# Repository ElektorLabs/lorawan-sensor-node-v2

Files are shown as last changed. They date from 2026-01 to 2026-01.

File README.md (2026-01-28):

# LoRa-Sensor-Node-v2




A comprehensive ESP32-S3 based sensor node that validates GPS positioning, LoRaWAN connectivity, SD card logging, battery charging, and deep-sleep power management without requiring the Arduino IDE.

## 🚀 Features

- **Multi-Peripheral Validation**: Powers and tests GPS, LoRa modem, SD logger, and battery charger
- **Smart Power Management**: Configurable deep-sleep cycles with peripheral power control
- **LoRaWAN Integration**: OTAA join with synthetic telemetry transmission
- **GPS Cold Start Handling**: Waits for valid GPS fix before LoRaWAN operations
- **Battery Management**: BQ25186 charger monitoring and configuration
- **Comprehensive Logging**: Tagged UART output and SD card data logging
- **Status Indicators**: LED patterns for system health monitoring

## 🔧 Hardware Components

### Core Platform
- **MCU**: ESP32-S3 Development Module
- **GPS Module**: Ebyte EWM108-GN05 (Allystar-compatible GNSS receiver)
- **LoRa Module**: Ebyte LoRaWAN module with AT command interface
- **Battery Charger**: BQ25186 Li-Ion battery management IC
- **Storage**: MicroSD card for data logging

### Pin Configuration

| Component | Pin | Function |
|---|-----|---|
| **Power Control** |
| I2C Enable | GPIO 38 | I2C bus power control |
| LoRa Enable | GPIO 6 | LoRa module power |
| GPS Enable | GPIO 7 | GPS module power |
| **Status LEDs** |
| Red LED | GPIO 48 | Error/fault indication |
| Green LED | GPIO 47 | System status |
| **I2C Bus** |
| SDA | GPIO 10 | I2C data line |
| SCL | GPIO 9 | I2C clock line |
| **SD Card (SPI)** |
| MOSI | GPIO 11 | SPI data out |
| SCK | GPIO 12 | SPI clock |
| MISO | GPIO 13 | SPI data in |
| CS | GPIO 8 | Chip select |
| **LoRa UART** |
| RX | GPIO 4 | LoRa module RX |
| TX | GPIO 5 | LoRa module TX |
| **GPS UART** |
| RX | GPIO 21 | GPS module RX |
| TX | GPIO 14 | GPS module TX |

## ⚙️ Configuration

All configuration is centralized in `config.h` using `constexpr` constants:

### Timing Parameters
```cpp
constexpr unsigned long kGpsColdStartMs = 60000;        // GPS cold start window
constexpr unsigned long kGpsLockTimeoutMs = 180000;     // GPS fix timeout
constexpr unsigned long kSensorAcquisitionMs = 15000;   // Sensor reading time
constexpr uint64_t kDeepSleepIntervalUs = 60ULL * 1000000ULL; // Sleep interval
constexpr unsigned long kLoraJoinRetryMs = 15000;       // LoRa join retry
```

### Power Management
```cpp
constexpr bool kEnableDeepSleep = true;     // Enable ESP32 deep sleep
constexpr bool kEnableStatusLeds = true;    // Enable LED indicators
constexpr float kChargeTargetCurrentMa = 520.0f;   // Battery charge current (5-1000 mA)
constexpr float kInputCurrentLimitMa = 665.0f;     // Input current limit (50-665 mA)
```

### LoRaWAN Credentials
```cpp
constexpr LoraCredentials kLoraCredentials{
    "xxxxxxxxxxxxxxxx",                    // Device EUI
    "0000000000000000",                    // Application EUI
    "xxxxxxxxxxxxxxxxxxxxxxxxxxxxxx",   // Application Key
};
```

### GPS Power Configuration
```cpp
constexpr AllystarGpsPowerConfig kGpsPowerConfig{
    true,    // Enable GPS sleep/wake commands
    90000,   // Sleep duration (90 seconds)
    0x01,    // Sleep action (deep sleep)
    0x11,    // Wake mode (start command)
};
```

## 🔄 Operation Flow

1. **System Wake**: ESP32 wakes from deep sleep, powers peripheral rails
2. **GPS Cold Start**: Waits for GPS module to acquire satellite fix
3. **LoRaWAN Join**: Performs OTAA join once GPS is ready (or timeout expires)
4. **Data Collection**: Gathers GPS coordinates and battery telemetry
5. **Transmission**: Sends telemetry via LoRaWAN uplink
6. **Logging**: Records data to SD card with timestamps
7. **Sleep Preparation**: Powers down GPS with Allystar sleep commands
8. **Deep Sleep**: ESP32 enters deep sleep for configured interval

## 📊 Serial Output

The firmware provides tagged serial output at 115200 baud:

```
[Pwr ] Wake reason: Timer
[GPS ] Powering GPS module...
[LoRa] Powering LoRa module...
[GPS ] NMEA: $GNGGA,123456.00,4012.34567,N,07412.34567,W,1,08,1.2,45.6,M,33.2,M,,*5A
[LoRa] AT+JOIN
[LoRa] Event: join confirmed
[LoRa] Sending telemetry: 4012.34567,-07412.34567,45.6,4.12,85
[Chg ] Battery: 4.12V, Charge: 85%, Temp: 25°C
[Pwr ] Entering deep sleep for 60 seconds
```

## 📁 File Structure

```
LoRa-SenseNode-v2/
├── LoRa-SenseNode-v2.ino    # Main firmware file
├── config.h                 # Configuration constants
├── Bq25186.h               # Battery charger interface
├── EbyteGpsParser.h        # GPS NMEA parser
├── LoraAtHelpers.h         # LoRaWAN AT command helpers
├── SdCardLogger.h          # SD card logging utilities
├── TaggedStream.h          # Serial output tagging
├── ProcessFlow.md          # Detailed process documentation
├── FirmwareOverview.md     # Architecture overview
└── docs/                   # Additional documentation
```

## 🔍 Troubleshooting

### LED Status Indicators
- **2 Red Blinks**: GPS fault or timeout
- **3 Red Blinks**: LoRa communication fault
- **Green Solid**: System operating normally
- **LEDs Off**: Status LEDs disabled in config

### Common Issues
1. **GPS Not Acquiring Fix**: Ensure clear sky view, check antenna connection
2. **LoRa Join Fails**: Verify credentials and gateway availability
3. **SD Card Errors**: Check card formatting (FAT32) and connections
4. **Power Issues**: Verify battery connection and charger configuration

### Debug Mode
Set `kEnableDebugSerial = true` and `kShowRawGps = true` in config.h for verbose output.

## 🛠️ Development

### Adding New Features
- Hardware tests: Create new sketches in `src/tests/<SketchName>/`
- Experiments: Use `src/claude-test/` for exploratory code
- Helper functions: Add to existing headers or create new ones as needed

### Testing Without Deep Sleep
Set `kEnableDeepSleep = false` in config.h to run continuous loops for bench testing.

## 📄 License

This project is licensed under the GNU License - see the [LICENSE](LICENSE) file for details.

## 🤝 Contributing

1. Fork the repository
2. Create a feature branch (`git checkout -b feature/amazing-feature`)
3. Commit your changes (`git commit -m 'Add amazing feature'`)
4. Push to the branch (`git push origin feature/amazing-feature`)
5. Open a Pull Request

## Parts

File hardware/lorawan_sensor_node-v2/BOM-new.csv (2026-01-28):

# | Reference | Qty | Manufacturer_Part_Number | Value | DNP | Exclude from BOM | Exclude from Board | Footprint | Datasheet | Mouser Part Number
1 | AE1 | 1 | 3-1478978-1 | 3-1478978-1 |  |  |  | SamacSys_Parts:314789781 | ~ | 571-3-1478978-1
2 | C1 | 1 | C1608X7R1H104K080AA | 100nF |  |  |  | Capacitor_SMD:C_0603_1608Metric | ~ | 810-C1608X7R1H104K
3 | C4 | 1 | C0402C103K5RAC7411 | 10nF |  |  |  | Capacitor_SMD:C_0402_1005Metric_Pad0.74x0.62mm_HandSolder | 80-C0402C103K5R7411 | 80-C0402C103K5R7411
4 | C5 | 1 | C1608X7R1H104K080AA | 0.1uF |  |  |  | Capacitor_SMD:C_0603_1608Metric | ~ | 810-C1608X7R1H104K
5 | C6 | 1 | 865080442004 | 22uF |  |  |  | SamacSys_Parts:CAPAE530X550N |  | 710-865080442004
6 | C7 | 1 | GRM219R60J476ME44 | 47uF |  |  |  | Capacitor_SMD:C_0805_2012Metric | ~
7 | C9 | 1 | GRM187R61A226ME15 | 22uF |  |  |  | Capacitor_SMD:C_0603_1608Metric | ~
8 | C13 | 1 | GRM155R60J475ME47D | 0.1uF |  |  |  | Capacitor_SMD:C_0402_1005Metric_Pad0.74x0.62mm_HandSolder | ~ | 81-GRM155R60J475ME7D
9 | C14 | 1 | GRM155R60J475ME47D | 100nF |  |  |  | Capacitor_SMD:C_0402_1005Metric_Pad0.74x0.62mm_HandSolder | ~ | 81-GRM155R60J475ME7D
10 | C15 | 1 | 600S560KT250T | 56pF |  |  |  | Capacitor_SMD:C_0603_1608Metric_Pad1.08x0.95mm_HandSolder | RF Capacitor | 581-600S560KT250T
11 | C16 | 1 | FM0V104ZF | FM0V104ZF |  |  |  | SamacSys_Parts:FM0V104ZF | https://content.kemet.com/datasheets/KEM_S6012_FM.pdf | 80-FM0V104ZF
12 | C18 | 1 | GRM155R60J475ME47D | 4.7uF |  |  |  | Capacitor_SMD:C_0402_1005Metric_Pad0.74x0.62mm_HandSolder | ~ | 81-GRM155R60J475ME7D
13 | C10,C11 | 2 | GRM155R60J475ME47D | 1uF |  |  |  | Capacitor_SMD:C_0402_1005Metric_Pad0.74x0.62mm_HandSolder | ~ | 81-GRM155R60J475ME7D
14 | C2,C3 | 2 | C0805C104M5RACTU | 0.1uF |  |  |  | Capacitor_SMD:C_0805_2012Metric_Pad1.18x1.45mm_HandSolder | ~ | 80-C0805C104M5R
15 | C8,C12,C17 | 3 | GRM155R60J475ME47D | 10uF |  |  |  | Capacitor_SMD:C_0402_1005Metric_Pad0.74x0.62mm_HandSolder | ~ | 81-GRM155R60J475ME7D
16 | D1 | 1 | SMF05C.TCT | SMF05C.TCT |  |  |  | SamacSys_Parts:SOT65P210X110-6N | https://www.mouser.co.uk/datasheet/2/761/smf05c-1278099.pdf | 947-SMF05C.TCT
17 | D4 | 1 | PMEG2010ER,115 | PMEG2010ER,115 |  |  |  | SamacSys_Parts:PMEG2010ER115 | ~ | 771-PMEG2010ER115
18 | D2,D3 | 2 | CUHS20S30,H3F | CUHS20S30,H3F |  |  |  | SamacSys_Parts:CUHS20S40H3F |  | 757-CUHS20S30H3F
19 | IC1 | 1 | TPL5110QDDCRQ1 | TPL5110QDDCRQ1 |  |  |  | SamacSys_Parts:SOT95P280X110-6N | http://www.ti.com/lit/gpn/tpl5110-q1 | 595-TPL5110QDDCRQ1
20 | IC2 | 1 | TPS22917DBV | TPS22917DBV (L) |  |  |  | Package_TO_SOT_SMD:SOT-23-6 | http://www.ti.com/lit/ds/symlink/tps22917.pdf
21 | IC3 | 1 | TPS631000DRLR | TPS631000DRLR |  |  |  | SamacSys_Parts:SOTFL50P160X60-8N | https://www.ti.com/lit/ds/symlink/tps631000.pdf?ts=1652152702265 | 595-TPS631000DRLR
22 | IC4 | 1 | BQ25186DLHR | BQ25186DLHR |  |  |  | SamacSys_Parts:SON40P220X200X80-11N | https://www.ti.com/lit/ds/symlink/bq25186.pdf?ts=1740508135755 | 595-BQ25186DLHR
23 | IC5,IC6,IC7 | 3 | TPS22919DCKR | TPS22919DCKR |  |  |  | SamacSys_Parts:SOT65P210X110-6N | http://www.ti.com/lit/ds/symlink/tps22919.pdf | 595-TPS22919DCKR
24 | K2 | 1 | PinHeader_2x03_P2.54mm_Vertical | PROG |  |  |  | Connector_PinHeader_2.54mm:PinHeader_2x03_P2.54mm_Vertical | ~
25 | K5 | 1 | JST_SH_SM04B-SRSS-TB_1x04-1MP_P1.00mm_Horizontal | Qwiic |  |  |  | Connector_JST:JST_SH_SM04B-SRSS-TB_1x04-1MP_P1.00mm_Horizontal | ~
26 | K6 | 1 | MEM2085-00-115-00-A | MEM2085-00-115-00-A |  |  |  | SamacSys_Parts:MEM20850011500A | https://gct.co/files/drawings/mem2085.pdf | 640-MEM20850011500A
27 | K7 | 1 | JST_PH_S2B-PH-K_1x02_P2.00mm_Horizontal | Solar Panel |  |  |  | Connector_JST:JST_PH_S2B-PH-K_1x02_P2.00mm_Horizontal | ~
28 | K8 | 1 | UJ20-C-H-C-3-SMT-TR | UJ20-C-H-C-3-SMT-TR |  |  |  | External Library:CUI_UJ20-C-H-C-3-SMT-TR
29 | K9 | 1 | JST_PH_S2B-PH-K_1x02_P2.00mm_Horizontal | Battery |  |  |  | Connector_JST:JST_PH_S2B-PH-K_1x02_P2.00mm_Horizontal | ~
30 | K10 | 1 | Connector_JST:JST_PH_S4B-PH-SM4-TB_1x04-1MP_P2.00mm_Horizontal | LORA UART |  |  |  | Connector_JST:JST_PH_S4B-PH-SM4-TB_1x04-1MP_P2.00mm_Horizontal | ~
31 | K12 | 1 | Connector_JST:JST_PH_S4B-PH-SM4-TB_1x04-1MP_P2.00mm_Horizontal | GPS UART |  |  |  | Connector_JST:JST_PH_S4B-PH-SM4-TB_1x04-1MP_P2.00mm_Horizontal | ~
32 | K1,K3,K4 | 3 | JST_PH_S4B-PH-SM4-TB_1x04-1MP_P2.00mm_Horizontal | IO |  |  |  | Connector_JST:JST_PH_S4B-PH-SM4-TB_1x04-1MP_P2.00mm_Horizontal | ~
33 | L1 | 1 | DFE201610P-1R0M=P2 | 1uH |  |  |  | SamacSys_Parts:1285ASH1R0MP2 | ~ | 81-DFE201610P-1R0MP2
34 | L2 | 1 | AIMC-0402-82NJ-T | AIMC-0402-82NJ-T |  |  |  | SamacSys_Parts:INDC1005X65N | ~
35 | LED1 | 1 | NCD0805G1 | NCD0805G1 |  |  |  | LED_SMD:LED_0805_2012Metric_Pad1.15x1.40mm_HandSolder | ~
36 | LED2 | 1 | NCD0805R1 | NCD0805R1 |  |  |  | LED_SMD:LED_0805_2012Metric_Pad1.15x1.40mm_HandSolder | ~
37 | MOD1 | 1 | ESP32-S3-WROOM-1 | ESP32-S3-WROOM-1 |  |  |  | RF_Module:ESP32-S3-WROOM-1 | https://www.espressif.com/sites/default/files/documentation/esp32-s3-wroom-1_wroom-1u_datasheet_en.pdf
38 | MOD2 | 1 | RAK3172 | ~ |  |  |  | RF_Module:RAK3172
39 | MOD3 | 1 | EWM108-GN05 | EWM108-GN05 |  |  |  | EWM108-GN05:PCBComponent_1 | https://www.cdebyte.com/products/EWM108-GN05/2#Pin
40 | R9 | 1 | RK73H1ETTP5762F | 57k |  |  |  | Resistor_SMD:R_0402_1005Metric | ~ | 660-RK73H1ETTP5762F
41 | R10 | 1 | CRCW040224R0FKED | 24R |  |  |  | Resistor_SMD:R_0402_1005Metric | ~ | 71-CRCW040224R0FKED
42 | R11 | 1 | ERJ-2RKF5113X | 511k |  |  |  | Resistor_SMD:R_0402_1005Metric | ~ | 667-ERJ-2RKF5113X
43 | R12 | 1 | ERJ-2RKF9102X | 91k |  |  |  | Resistor_SMD:R_0402_1005Metric | ~ | 667-ERJ-2RKF9102X
44 | R15 | 1 | RCS06034K70FKEA | 10k |  |  |  | Resistor_SMD:R_0402_1005Metric | ~ | 71-RCS06034K70FKEA
45 | R1,R2,R4,R16 | 4 | RCS060310K0FKEA | 10k |  |  |  | Resistor_SMD:R_0603_1608Metric | ~ | 71-RCS060310K0FKEA,71-RCS060310K0JNEA
46 | R13,R14 | 2 | RCS06034K70FKEA | 4.7k |  |  |  | Resistor_SMD:R_0603_1608Metric | ~ | 71-RCS06034K70FKEA
47 | R3,R5,R8 | 3 | MCT0603PD1000DP500 | 100R |  |  |  | Resistor_SMD:R_0603_1608Metric | ~ | 594-MCT0603PD1000DP5
48 | R6,R7 | 2 | CHP0805-FX-1001ELF | 1k |  |  |  | Resistor_SMD:R_0805_2012Metric_Pad1.20x1.40mm_HandSolder | ~ | 652-CHP0805FX1001ELF
49 | SW1 | 1 | SKRKAEE020 | BOOT |  |  |  | SamacSys_Parts:SKRKAEE020 | ~ | SKRKAEE020
50 | SW2 | 1 | SKRKAEE020 | EN |  |  |  | SamacSys_Parts:SKRKAEE020 | ~ | SKRKAEE020
51 | SW3 | 1 | SKRKAEE020 | WAKE UP |  |  |  | SamacSys_Parts:SKRKAEE020 | ~ | SKRKAEE020
52 | T1 | 1 | IRLML9301TRPBF | IRLML9301TRPBF |  |  |  | SamacSys_Parts:SOT95P237X112-3N | http://www.infineon.com/dgdl/irlml9301pbf.pdf?fileId=5546d462533600a401535668e5e42640 | 942-IRLML9301TRPBF

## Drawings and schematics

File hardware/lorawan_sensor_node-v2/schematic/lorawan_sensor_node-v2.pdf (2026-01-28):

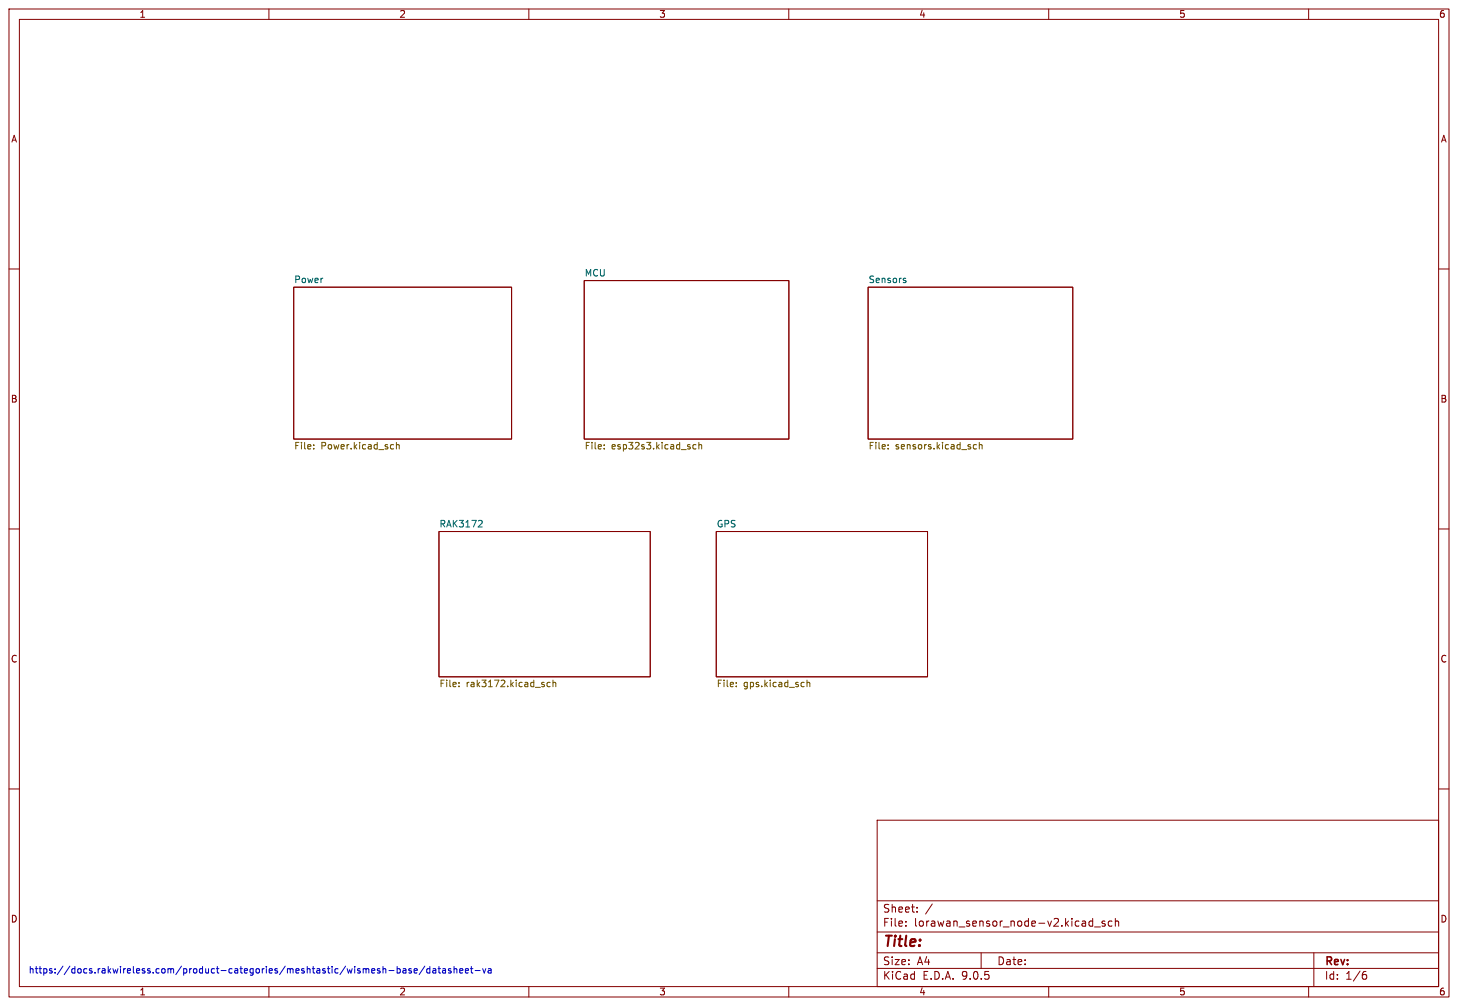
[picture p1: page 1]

https://docs.rakwireless.com/product-categories/meshtastic/wismesh-base/datasheet-va

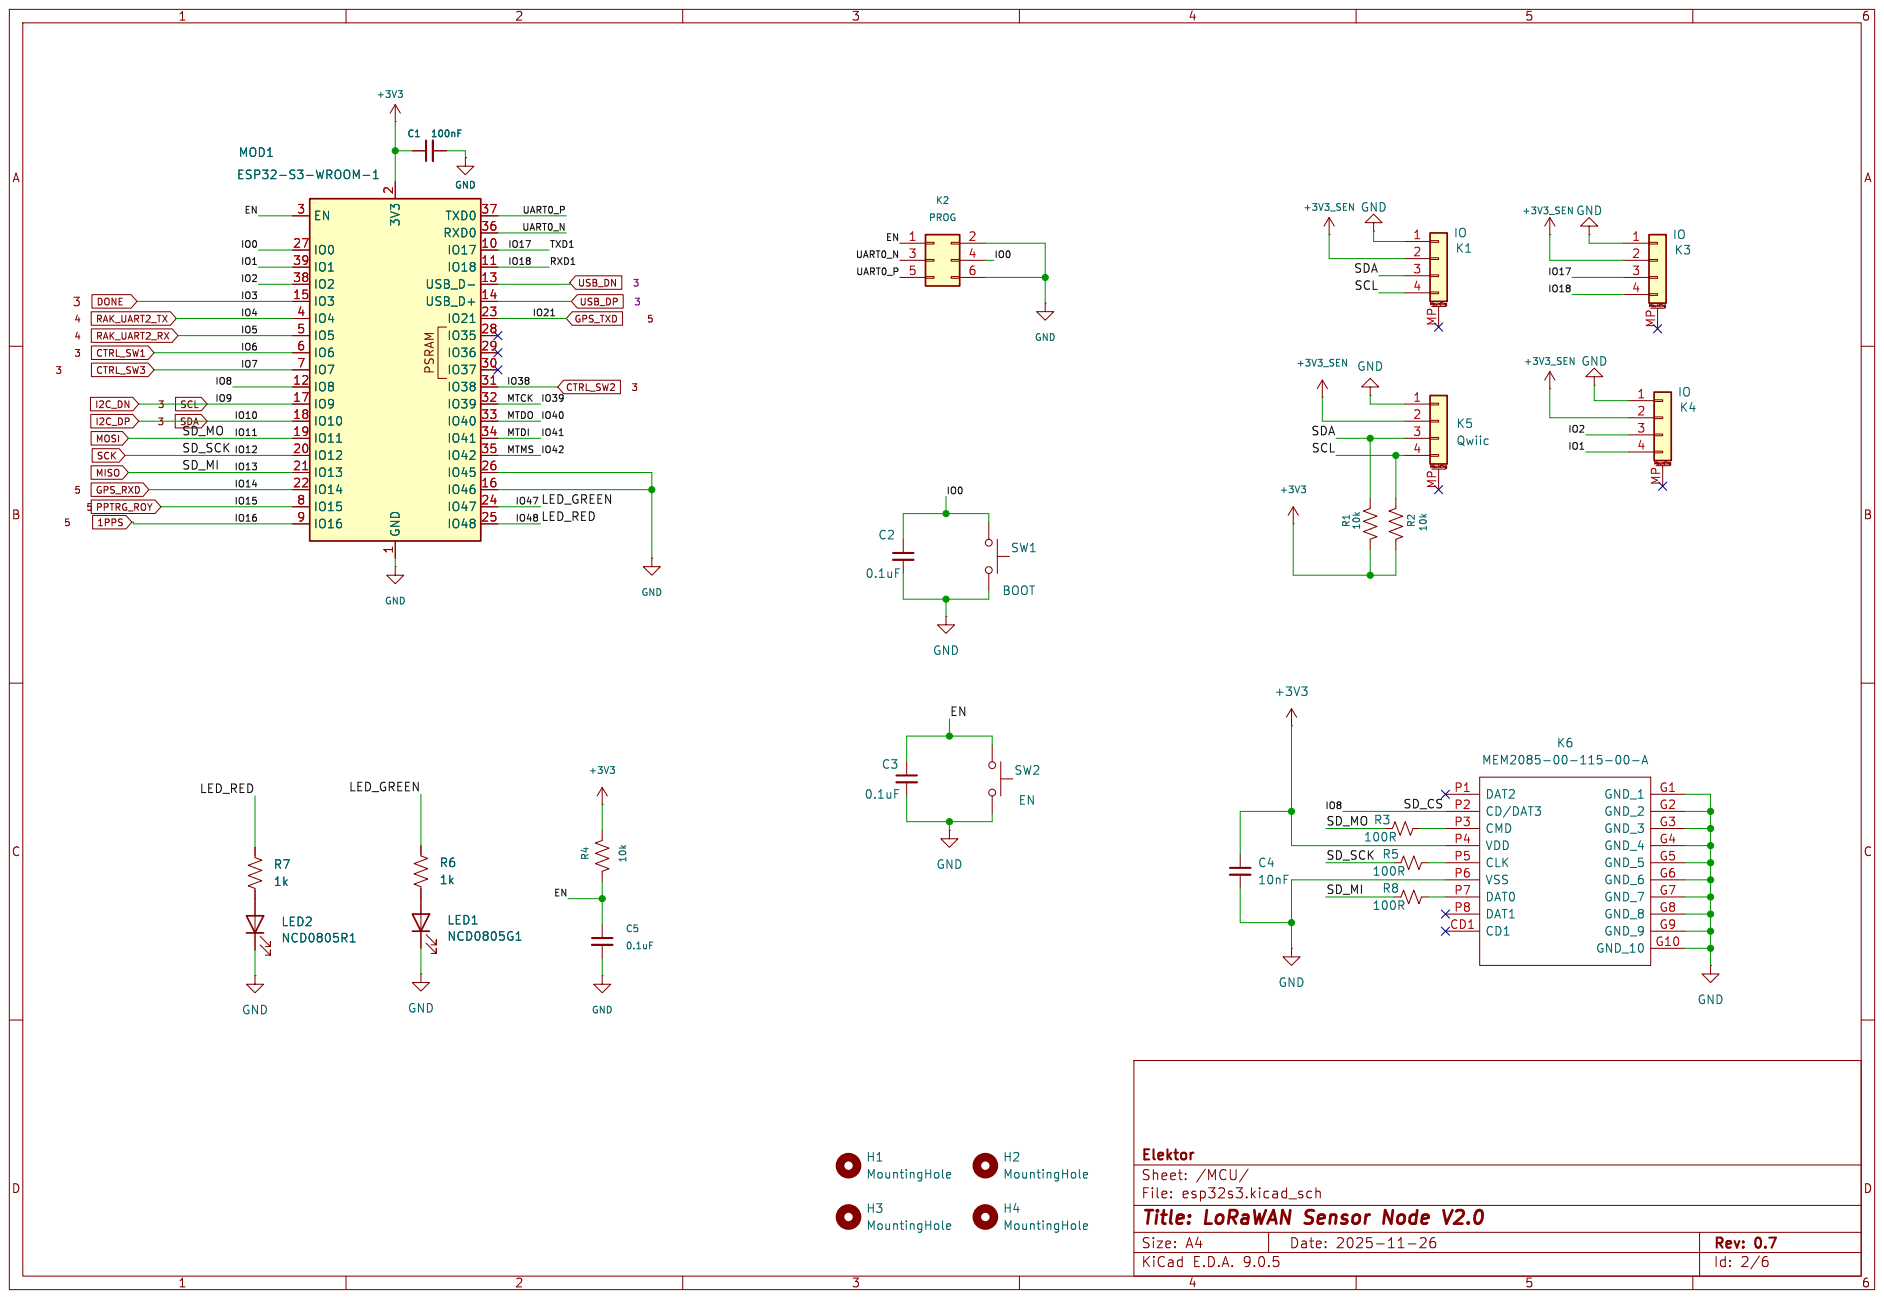
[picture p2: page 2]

File: esp32s3.kicad_sch Sheet: /MCU/ Elektor

Id: 2/6 Title: LoRaWAN Sensor Node V2.0

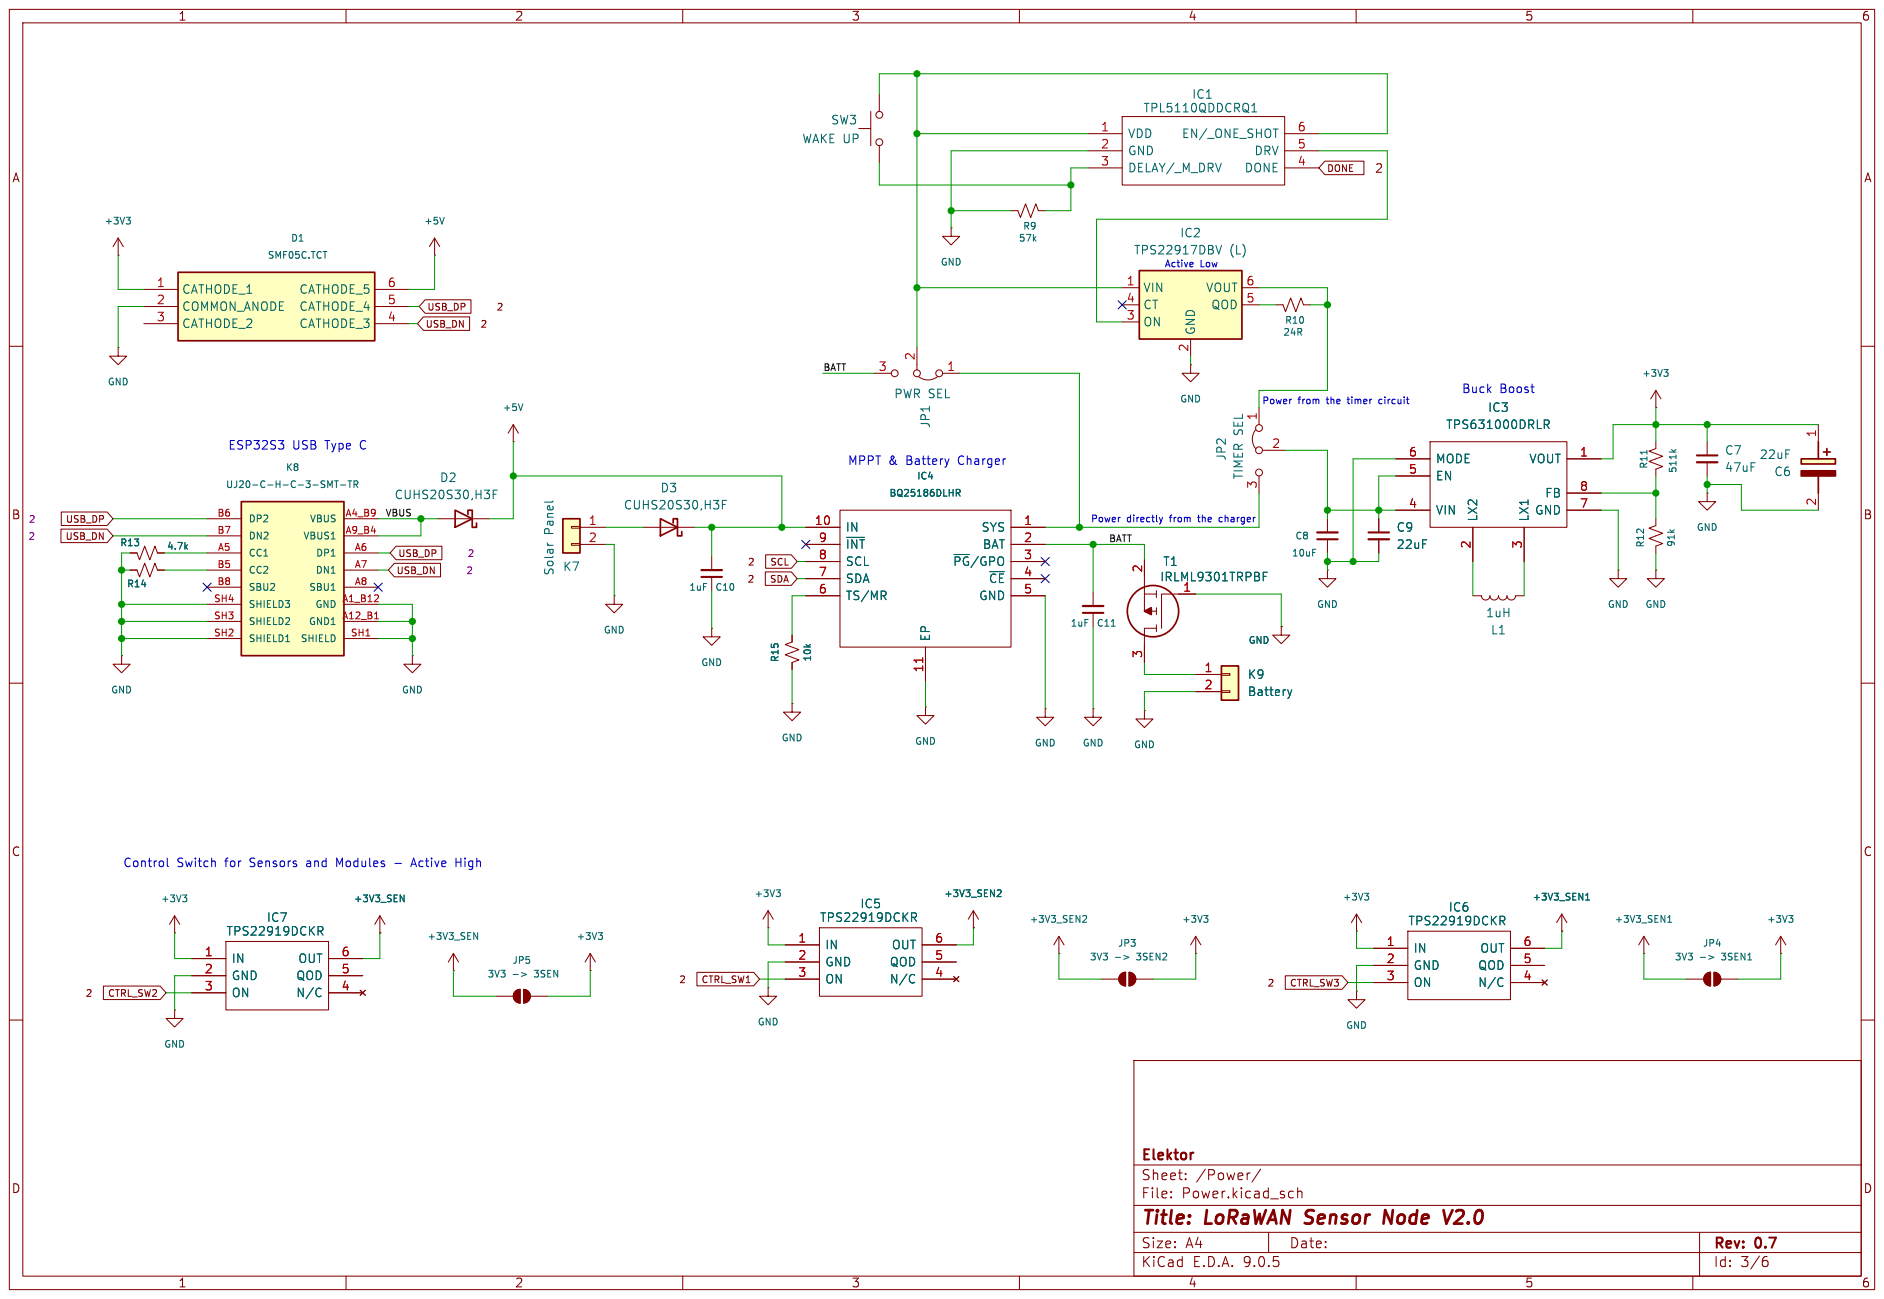
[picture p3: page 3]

File: Power.kicad_sch Sheet: /Power/ Elektor

Id: 3/6 Title: LoRaWAN Sensor Node V2.0

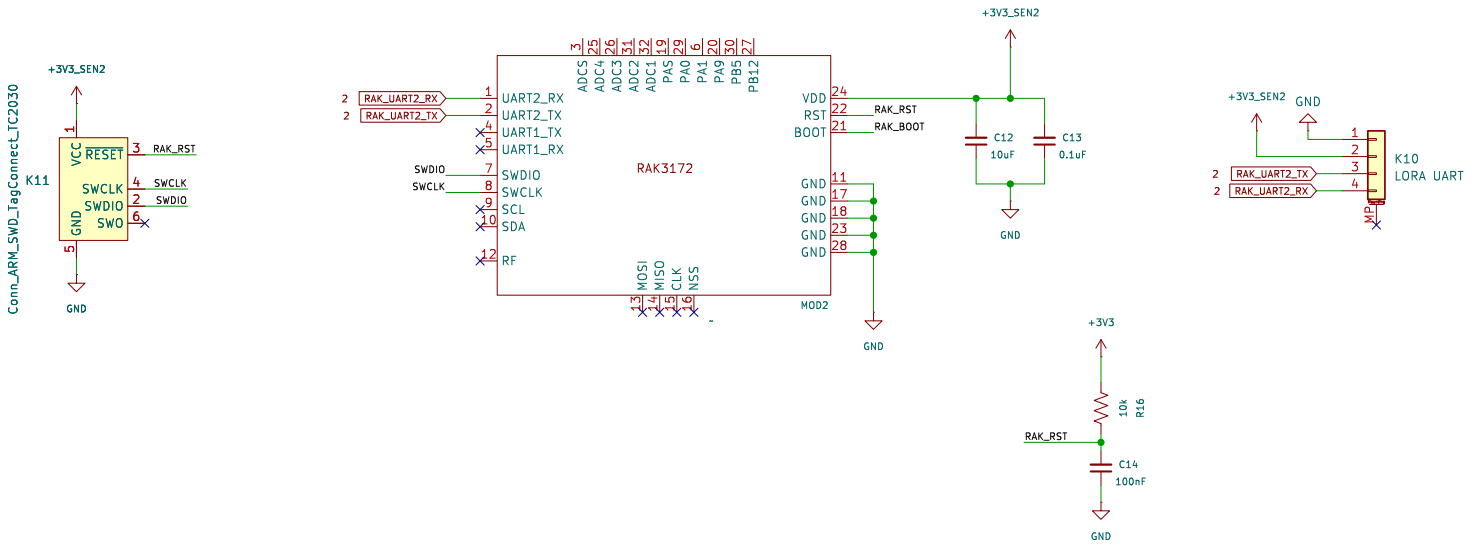
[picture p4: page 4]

3 ADC4 25 ADC3 26 ADC2 31 MOSI 13 ADC1 32 MISO 14 PAS 19 CLK 15 PA0 29 NSS 16 PA1

6 PA9 20 PB5 30 PB12 27 VDD 24 RST 22 BOOT 21 GND 11 GND 17 GND 18 GND 23 GND 28 MOD2 ~

5 ~{RESET}3 SWCLK 4 SWDIO 2 SWO 6 K11 Conn_ARM_SWD_TagConnect_TC2030 2 RAK_UART2_RX

5 ~{RESET}3 SWCLK 4 SWDIO 2 SWO 6 GND

Id: 4/6 Title: LoRaWAN Sensor Node V2.0

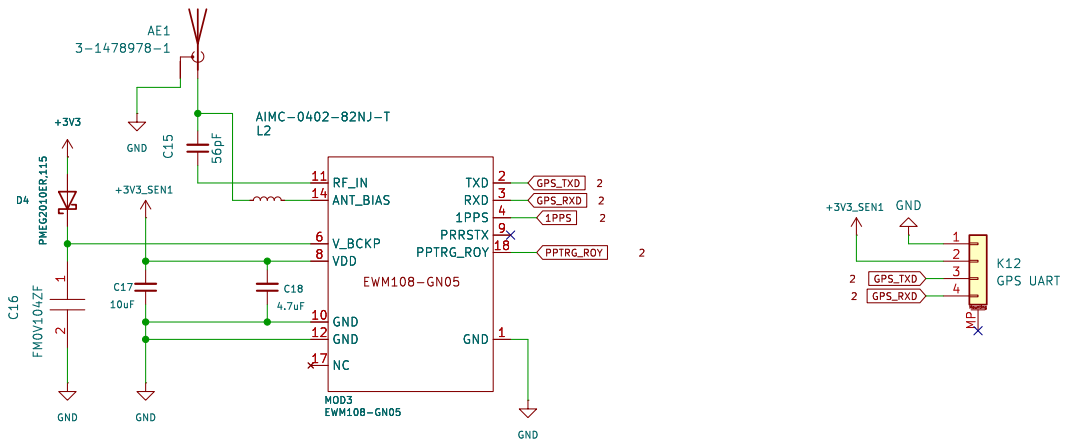
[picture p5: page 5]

Id: 5/6 Title: LoRaWAN Sensor Node V2.0

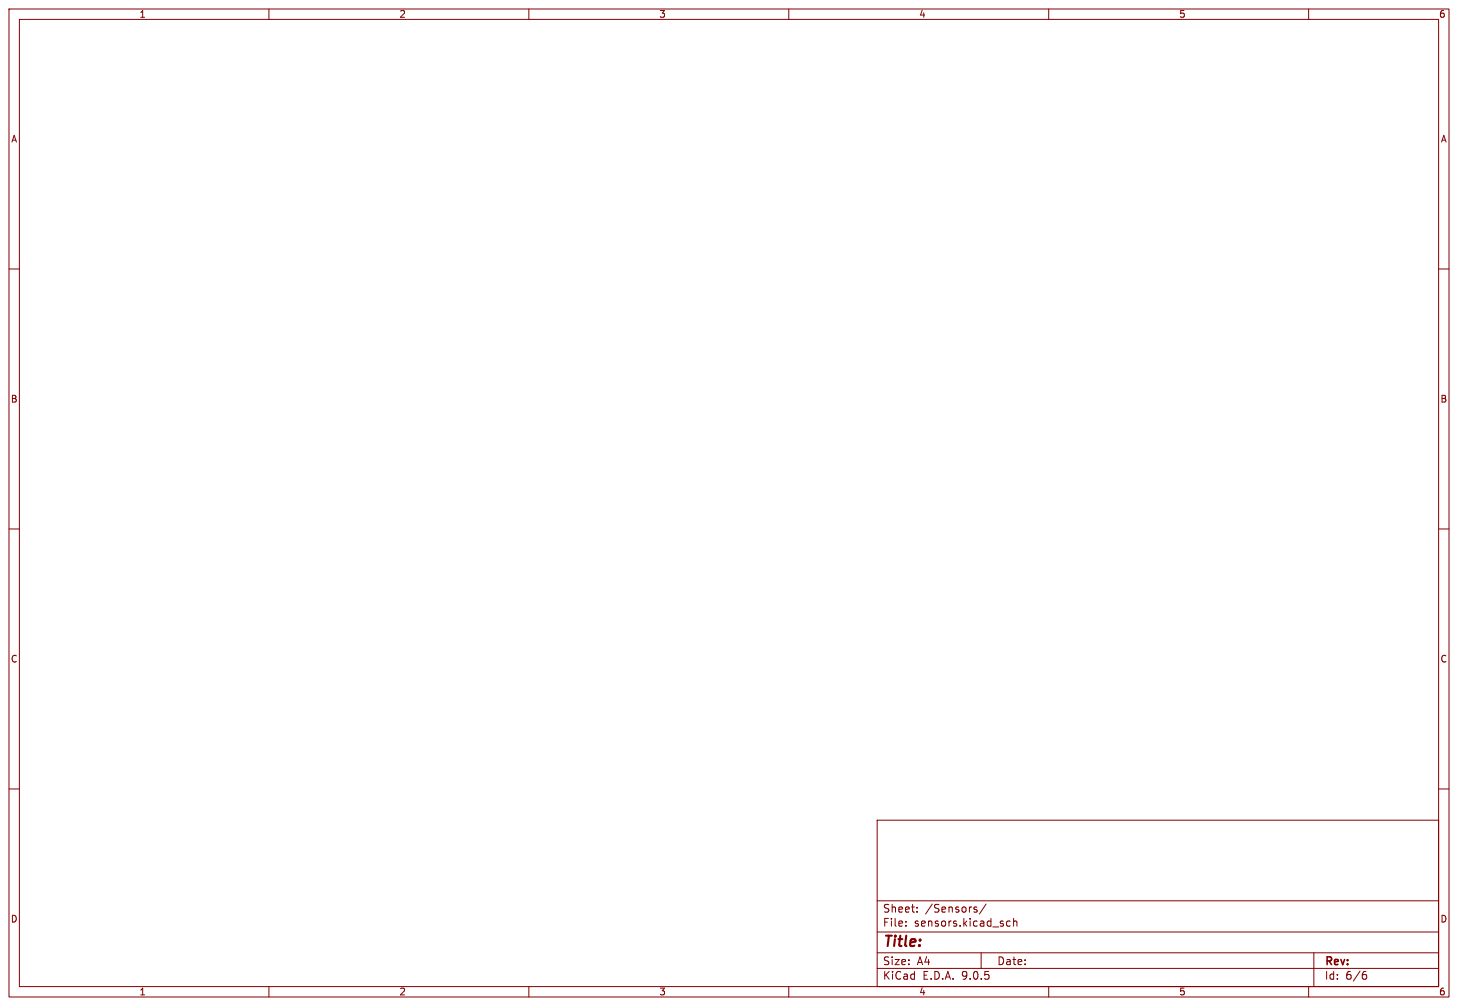
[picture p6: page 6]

Id: 6/6 Title: File: sensors.kicad_sch Sheet: /Sensors/

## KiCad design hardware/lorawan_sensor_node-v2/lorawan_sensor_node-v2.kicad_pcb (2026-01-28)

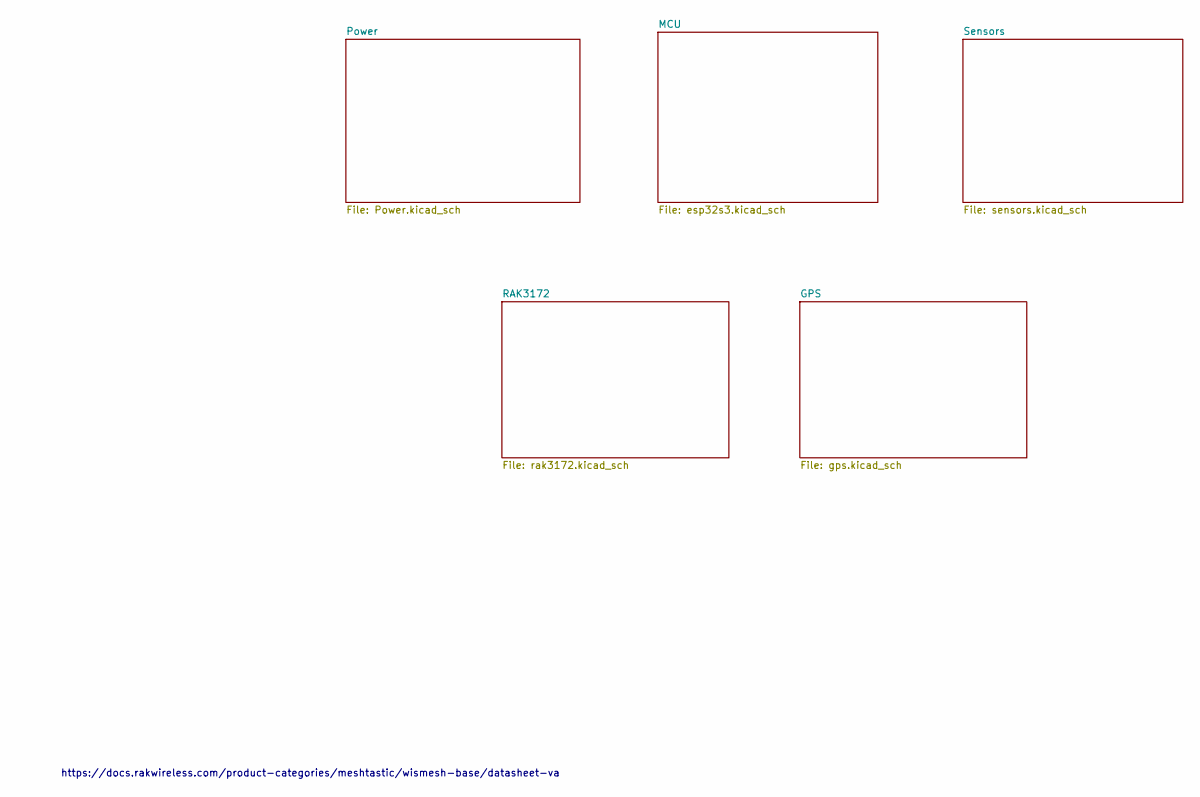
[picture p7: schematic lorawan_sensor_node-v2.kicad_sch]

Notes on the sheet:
https://docs.rakwireless.com/product-categories/meshtastic/wismesh-base/datasheet-va

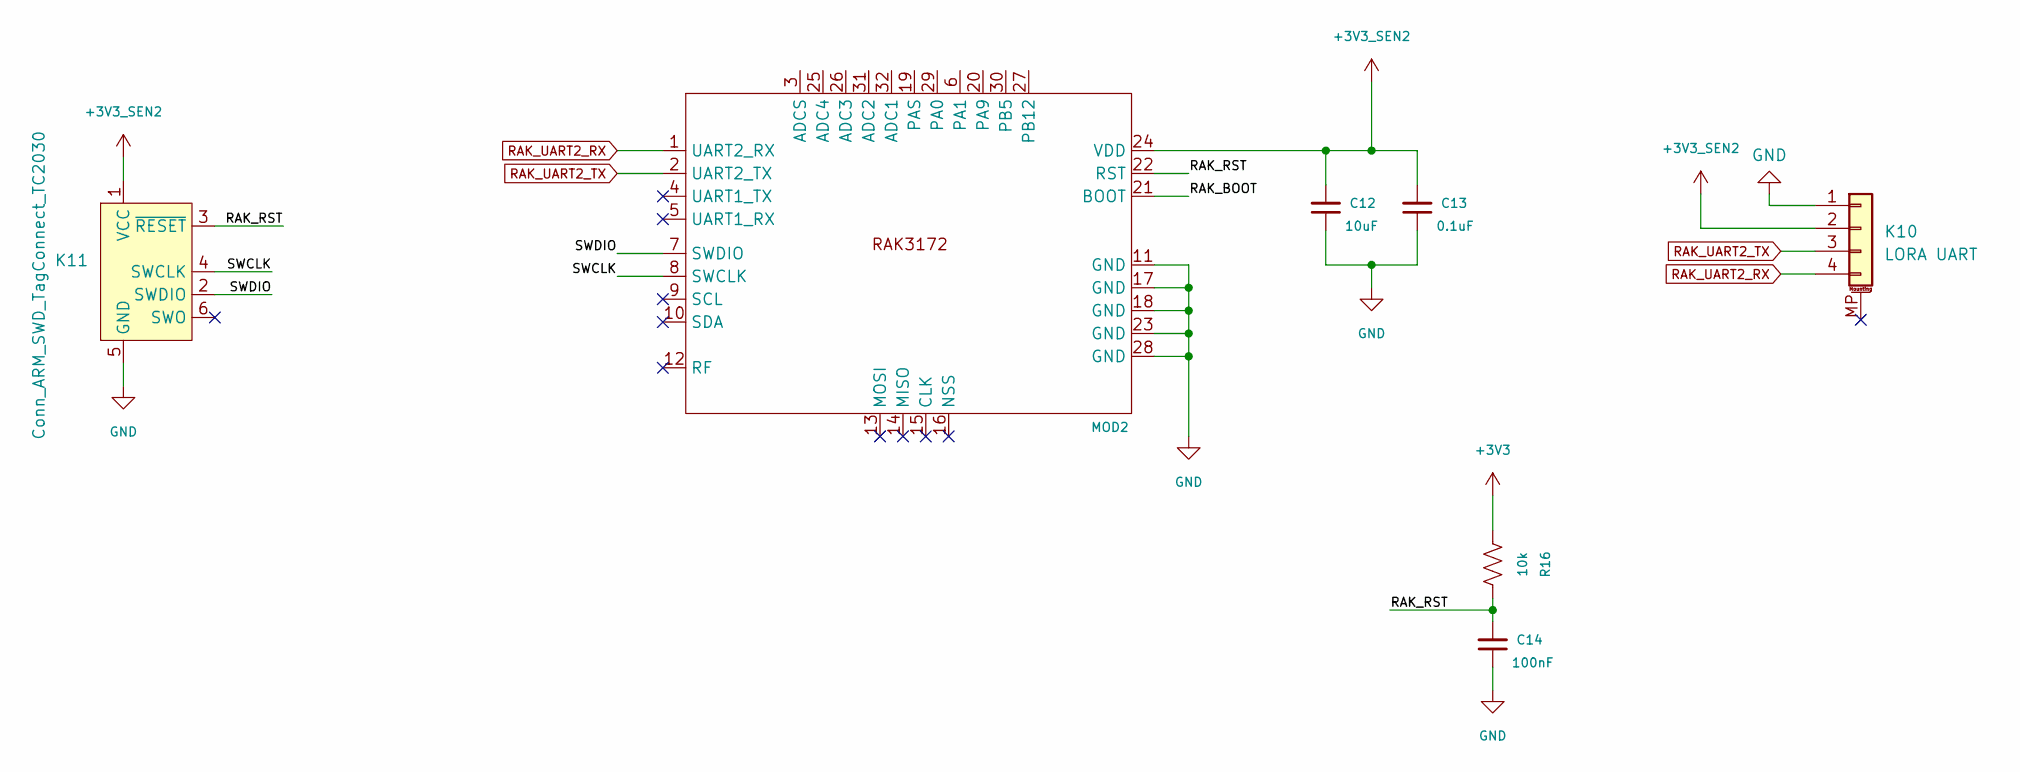
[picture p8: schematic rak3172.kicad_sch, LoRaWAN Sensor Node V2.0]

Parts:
C12: 10uF; C_0402_1005Metric_Pad0.74x0.62mm_HandSolder; Mouser Part Number 81-GRM155R60J475ME7D
C13: 0.1uF; C_0402_1005Metric_Pad0.74x0.62mm_HandSolder; Mouser Part Number 81-GRM155R60J475ME7D
C14: 100nF; C_0402_1005Metric_Pad0.74x0.62mm_HandSolder; Mouser Part Number 81-GRM155R60J475ME7D
K10: LORA UART; JST_PH_S4B-PH-SM4-TB_1x04-1MP_P2.00mm_Horizontal; Manufacturer_Part_Number Connector_JST:JST_PH_S4B-PH-SM4-TB_1x04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
K11: Conn_ARM_SWD_TagConnect_TC2030; Tag-Connect_TC2030-IDC-NL_2x03_P1.27mm_Vertical
MOD2: RAK3172; Manufacturer_Part_Number RAK3172
R16: 10k; R_0603_1608Metric; Manufacturer_Part_Number RCS060310K0FKEA; Mouser Part Number 71-RCS060310K0FKEA

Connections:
+3V3: R16.2; also elsewhere on the board
+3V3_SEN2: C12.2, C13.2, K10.2, K11.1 (VCC), MOD2.24 (VDD); also elsewhere on the board
/RAK3172/RAK_BOOT: MOD2.21 (BOOT)
/RAK3172/RAK_RST: C14.2, K11.3 (~RESET), MOD2.22 (RST), R16.1
/RAK3172/SWCLK: K11.4 (SWCLK), MOD2.8 (SWCLK)
/RAK3172/SWDIO: K11.2 (SWDIO), MOD2.7 (SWDIO)
GND: C12.1, C13.1, C14.1, K10.1, K11.5 (GND), MOD2.11 (GND), MOD2.17 (GND), MOD2.18 (GND), MOD2.23 (GND), MOD2.28 (GND); also elsewhere on the board
RAK_UART2_RX: K10.4, MOD2.1 (UART2_RX); also elsewhere on the board
RAK_UART2_TX: K10.3, MOD2.2 (UART2_TX); also elsewhere on the board

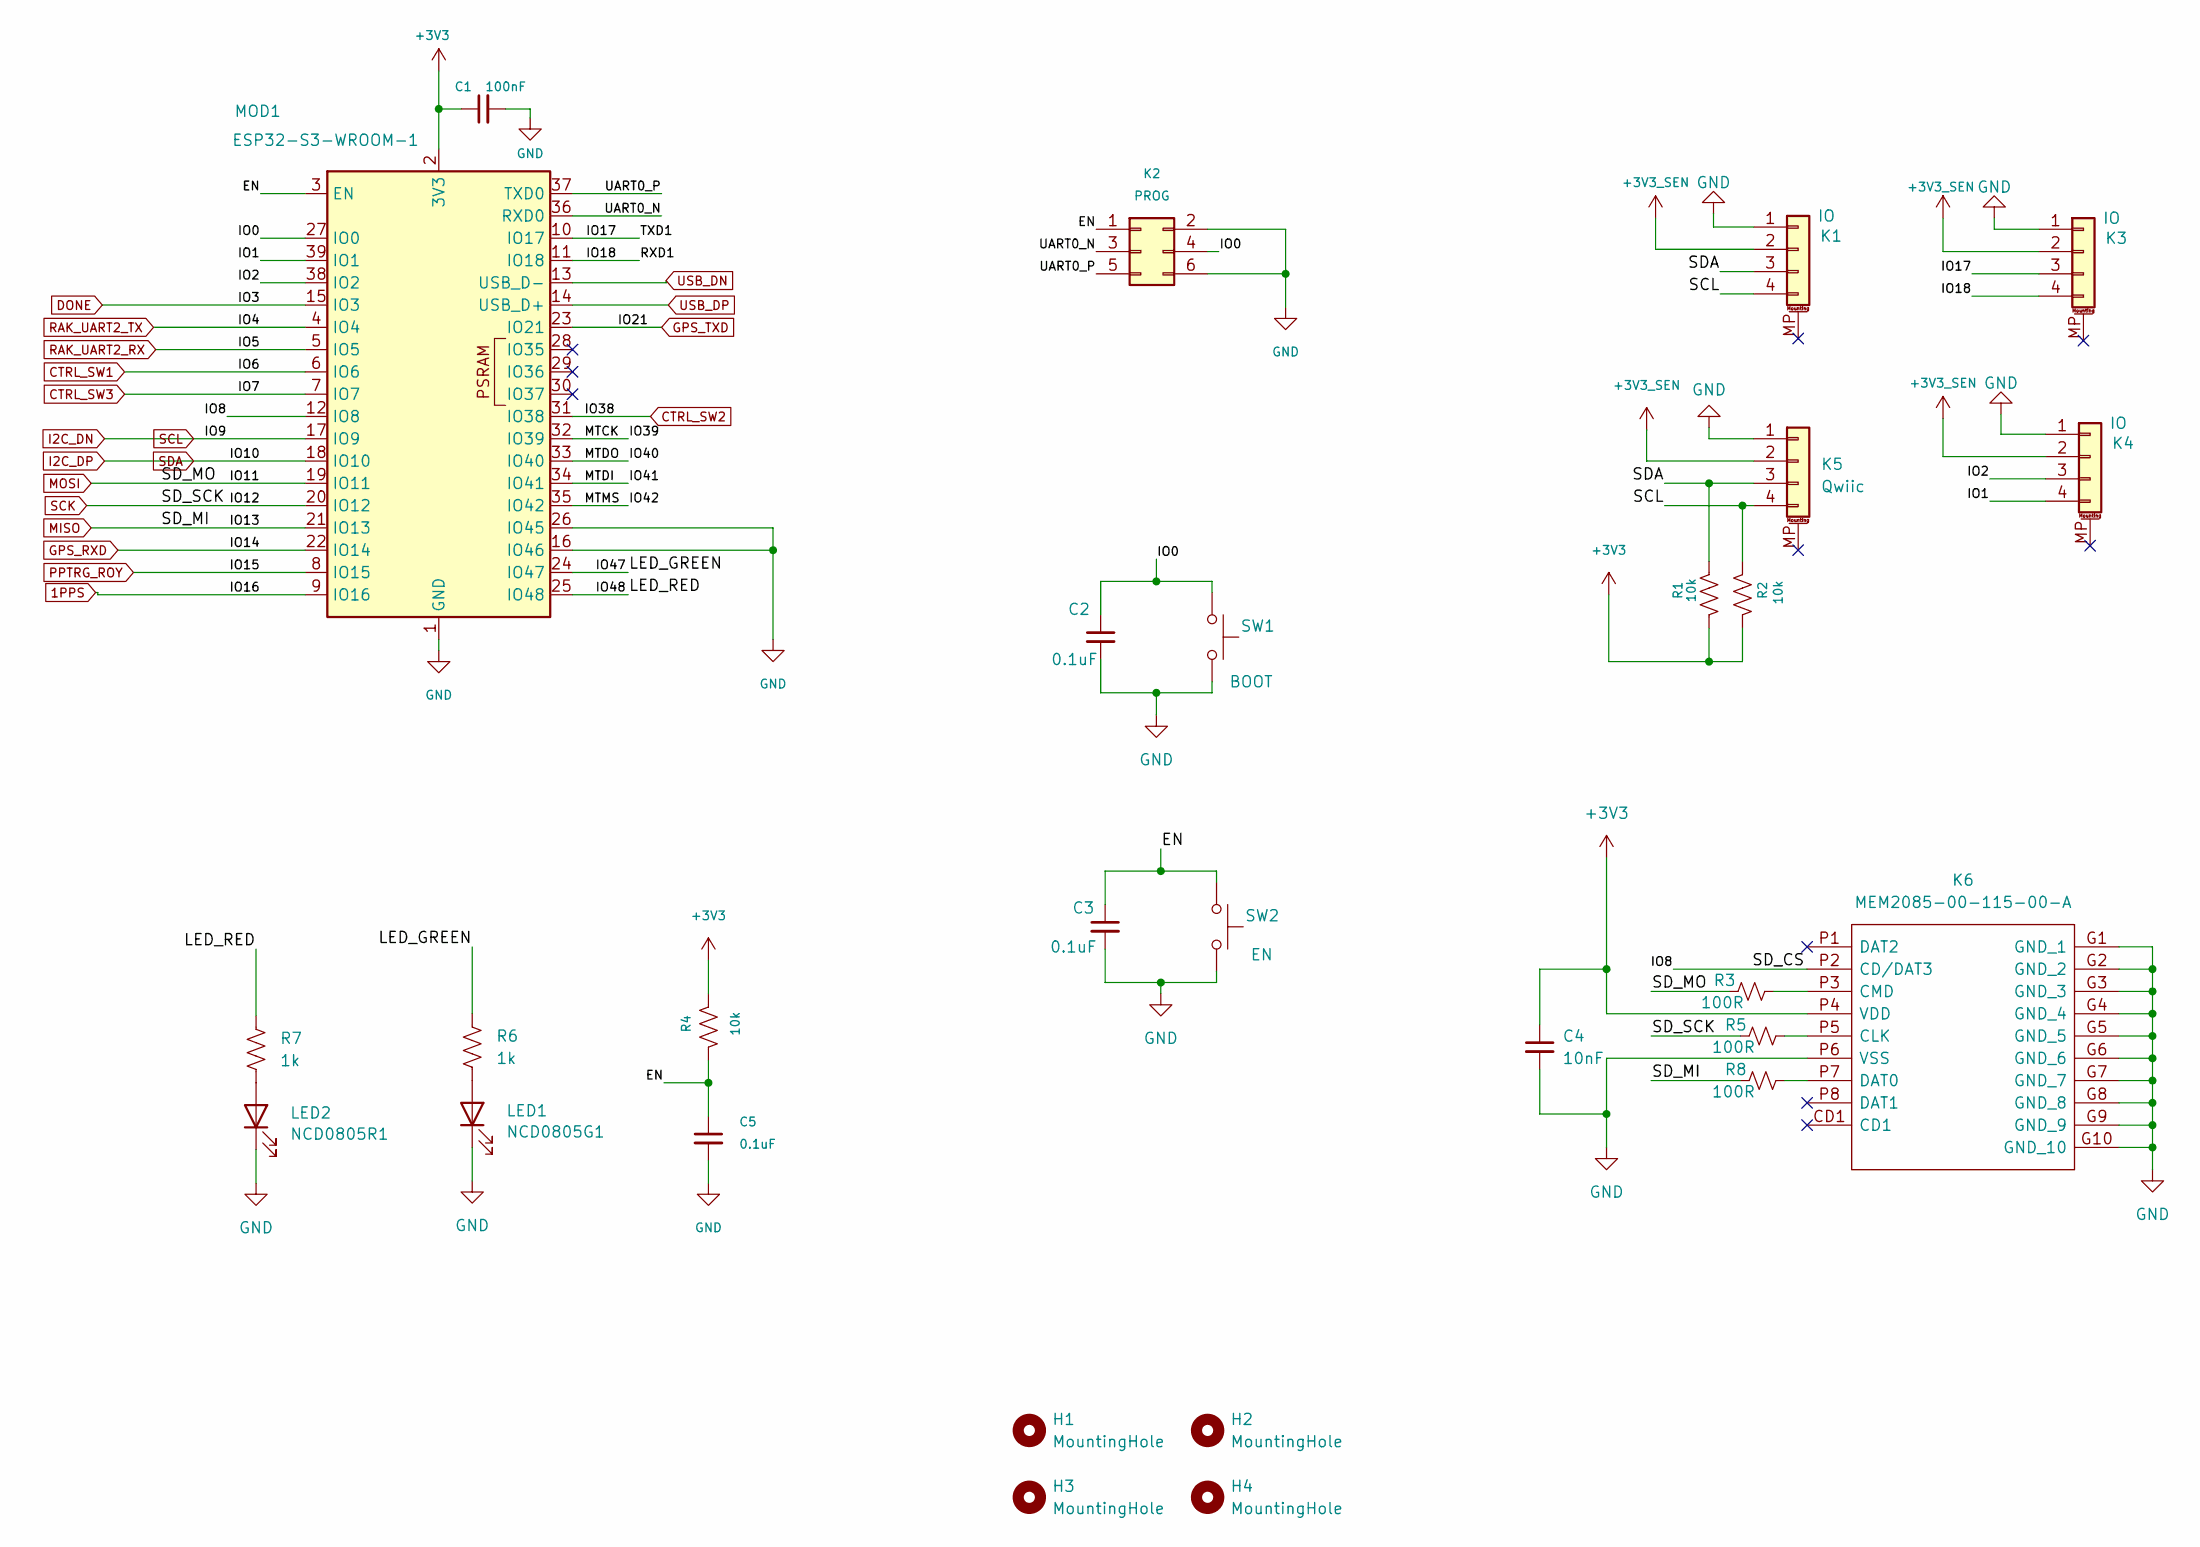
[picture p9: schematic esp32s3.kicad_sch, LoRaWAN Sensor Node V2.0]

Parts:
C1: 100nF; C_0603_1608Metric; Manufacturer_Part_Number C1608X7R1H104K080AA; Mouser Part Number 810-C1608X7R1H104K
C2, C3: 0.1uF; C_0805_2012Metric_Pad1.18x1.45mm_HandSolder; Manufacturer_Part_Number C0805C104M5RACTU; Mouser Part Number 80-C0805C104M5R
C4: 10nF; C_0402_1005Metric_Pad0.74x0.62mm_HandSolder; Manufacturer_Part_Number C0402C103K5RAC7411; Mouser Part Number 80-C0402C103K5R7411
C5: 0.1uF; C_0603_1608Metric; Manufacturer_Part_Number C1608X7R1H104K080AA; Mouser Part Number 810-C1608X7R1H104K
H1, H2, H3, H4: MountingHole; MountingHole_3.2mm_M3
K1, K3, K4: IO; JST_PH_S4B-PH-SM4-TB_1x04-1MP_P2.00mm_Horizontal; Manufacturer_Part_Number JST_PH_S4B-PH-SM4-TB_1x04-1MP_P2.00mm_H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
K2: PROG; PinHeader_2x03_P2.54mm_Vertical; Manufacturer_Part_Number PinHeader_2x03_P2.54mm_Vertical
K5: Qwiic; JST_SH_SM04B-SRSS-TB_1x04-1MP_P1.00mm_Horizontal; Manufacturer_Part_Number JST_SH_SM04B-SRSS-TB_1x04-1MP_P1.00mm_H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
K6: MEM2085-00-115-00-A; MEM20850011500A; Mouser Part Number 640-MEM20850011500A
LED1: NCD0805G1; LED_0805_2012Metric_Pad1.15x1.40mm_HandSolder; Manufacturer_Part_Number NCD0805G1
LED2: NCD0805R1; LED_0805_2012Metric_Pad1.15x1.40mm_HandSolder; Manufacturer_Part_Number NCD0805R1
MOD1: ESP32-S3-WROOM-1; Manufacturer_Part_Number ESP32-S3-WROOM-1
R1, R2, R4: 10k; R_0603_1608Metric; Manufacturer_Part_Number RCS060310K0FKEA; Mouser Part Number 71-RCS060310K0JNEA
R3, R5, R8: 100R; R_0603_1608Metric; Manufacturer_Part_Number MCT0603PD1000DP500; Mouser Part Number 594-MCT0603PD1000DP5
R6, R7: 1k; R_0805_2012Metric_Pad1.20x1.40mm_HandSolder; Manufacturer_Part_Number CHP0805-FX-1001ELF; Mouser Part Number 652-CHP0805FX1001ELF
SW1: BOOT; SKRKAEE020; Manufacturer_Part_Number SKRKAEE020; Mouser Part Number SKRKAEE020
SW2: EN; SKRKAEE020; Manufacturer_Part_Number SKRKAEE020; Mouser Part Number SKRKAEE020

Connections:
1PPS: MOD1.9 (IO16); also elsewhere on the board
+3V3: C1.1, C4.1, K6.P4 (VDD), MOD1.2 (3V3), R1.1, R2.1, R4.2; also elsewhere on the board
+3V3_SEN: K1.2, K3.2, K4.2, K5.2; also elsewhere on the board
/MCU/EN: C3.1, C5.1, K2.1, MOD1.3 (EN), R4.1, SW2.1
/MCU/IO0: C2.1, K2.4, MOD1.27 (IO0), SW1.1
/MCU/IO1: K4.4, MOD1.39 (IO1)
/MCU/IO2: K4.3, MOD1.38 (IO2)
/MCU/IO8: K6.P2 (CD/DAT3), MOD1.12 (IO8)
/MCU/IO17: K3.3, MOD1.10 (IO17)
/MCU/IO18: K3.4, MOD1.11 (IO18)
/MCU/IO39: MOD1.32 (IO39)
/MCU/IO40: MOD1.33 (IO40)
/MCU/IO41: MOD1.34 (IO41)
/MCU/IO42: MOD1.35 (IO42)
/MCU/IO47: MOD1.24 (IO47), R6.2
/MCU/IO48: MOD1.25 (IO48), R7.2
/MCU/UART0_N: K2.3, MOD1.36 (RXD0)
/MCU/UART0_P: K2.5, MOD1.37 (TXD0)
CTRL_SW1: MOD1.6 (IO6); also elsewhere on the board
CTRL_SW2: MOD1.31 (IO38); also elsewhere on the board
CTRL_SW3: MOD1.7 (IO7); also elsewhere on the board
DONE: MOD1.15 (IO3); also elsewhere on the board
GND: C1.2, C2.2, C3.2, C4.2, C5.2, K1.1, K2.2, K2.6, K3.1, K4.1, K5.1, K6.G1 (GND_1), K6.G2 (GND_2), K6.G3 (GND_3), K6.G4 (GND_4), K6.G5 (GND_5), K6.G6 (GND_6), K6.G7 (GND_7), K6.G8 (GND_8), K6.G9 (GND_9), K6.G10 (GND_10), K6.P6 (VSS), LED1.1 (K), LED2.1 (K), MOD1.1 (GND), MOD1.16 (IO46), MOD1.26 (IO45), MOD1.40 (GND), MOD1.41 (GND), SW1.2, SW2.2; also elsewhere on the board
GPS_RXD: MOD1.22 (IO14); also elsewhere on the board
GPS_TXD: MOD1.23 (IO21); also elsewhere on the board
I2C_DN: K1.4, K5.4, MOD1.17 (IO9), R2.2; also elsewhere on the board
I2C_DP: K1.3, K5.3, MOD1.18 (IO10), R1.2; also elsewhere on the board
MISO: MOD1.21 (IO13), R8.1
MOSI: MOD1.19 (IO11), R3.1
unnamed: K6.P5 (CLK), R5.2
unnamed: K6.P3 (CMD), R3.2
unnamed: K6.P7 (DAT0), R8.2
unnamed: LED1.2 (A), R6.1
unnamed: LED2.2 (A), R7.1
PPTRG_ROY: MOD1.8 (IO15); also elsewhere on the board
RAK_UART2_RX: MOD1.5 (IO5); also elsewhere on the board
RAK_UART2_TX: MOD1.4 (IO4); also elsewhere on the board
SCK: MOD1.20 (IO12), R5.1
USB_DN: MOD1.13 (USB_D-); also elsewhere on the board
USB_DP: MOD1.14 (USB_D+); also elsewhere on the board

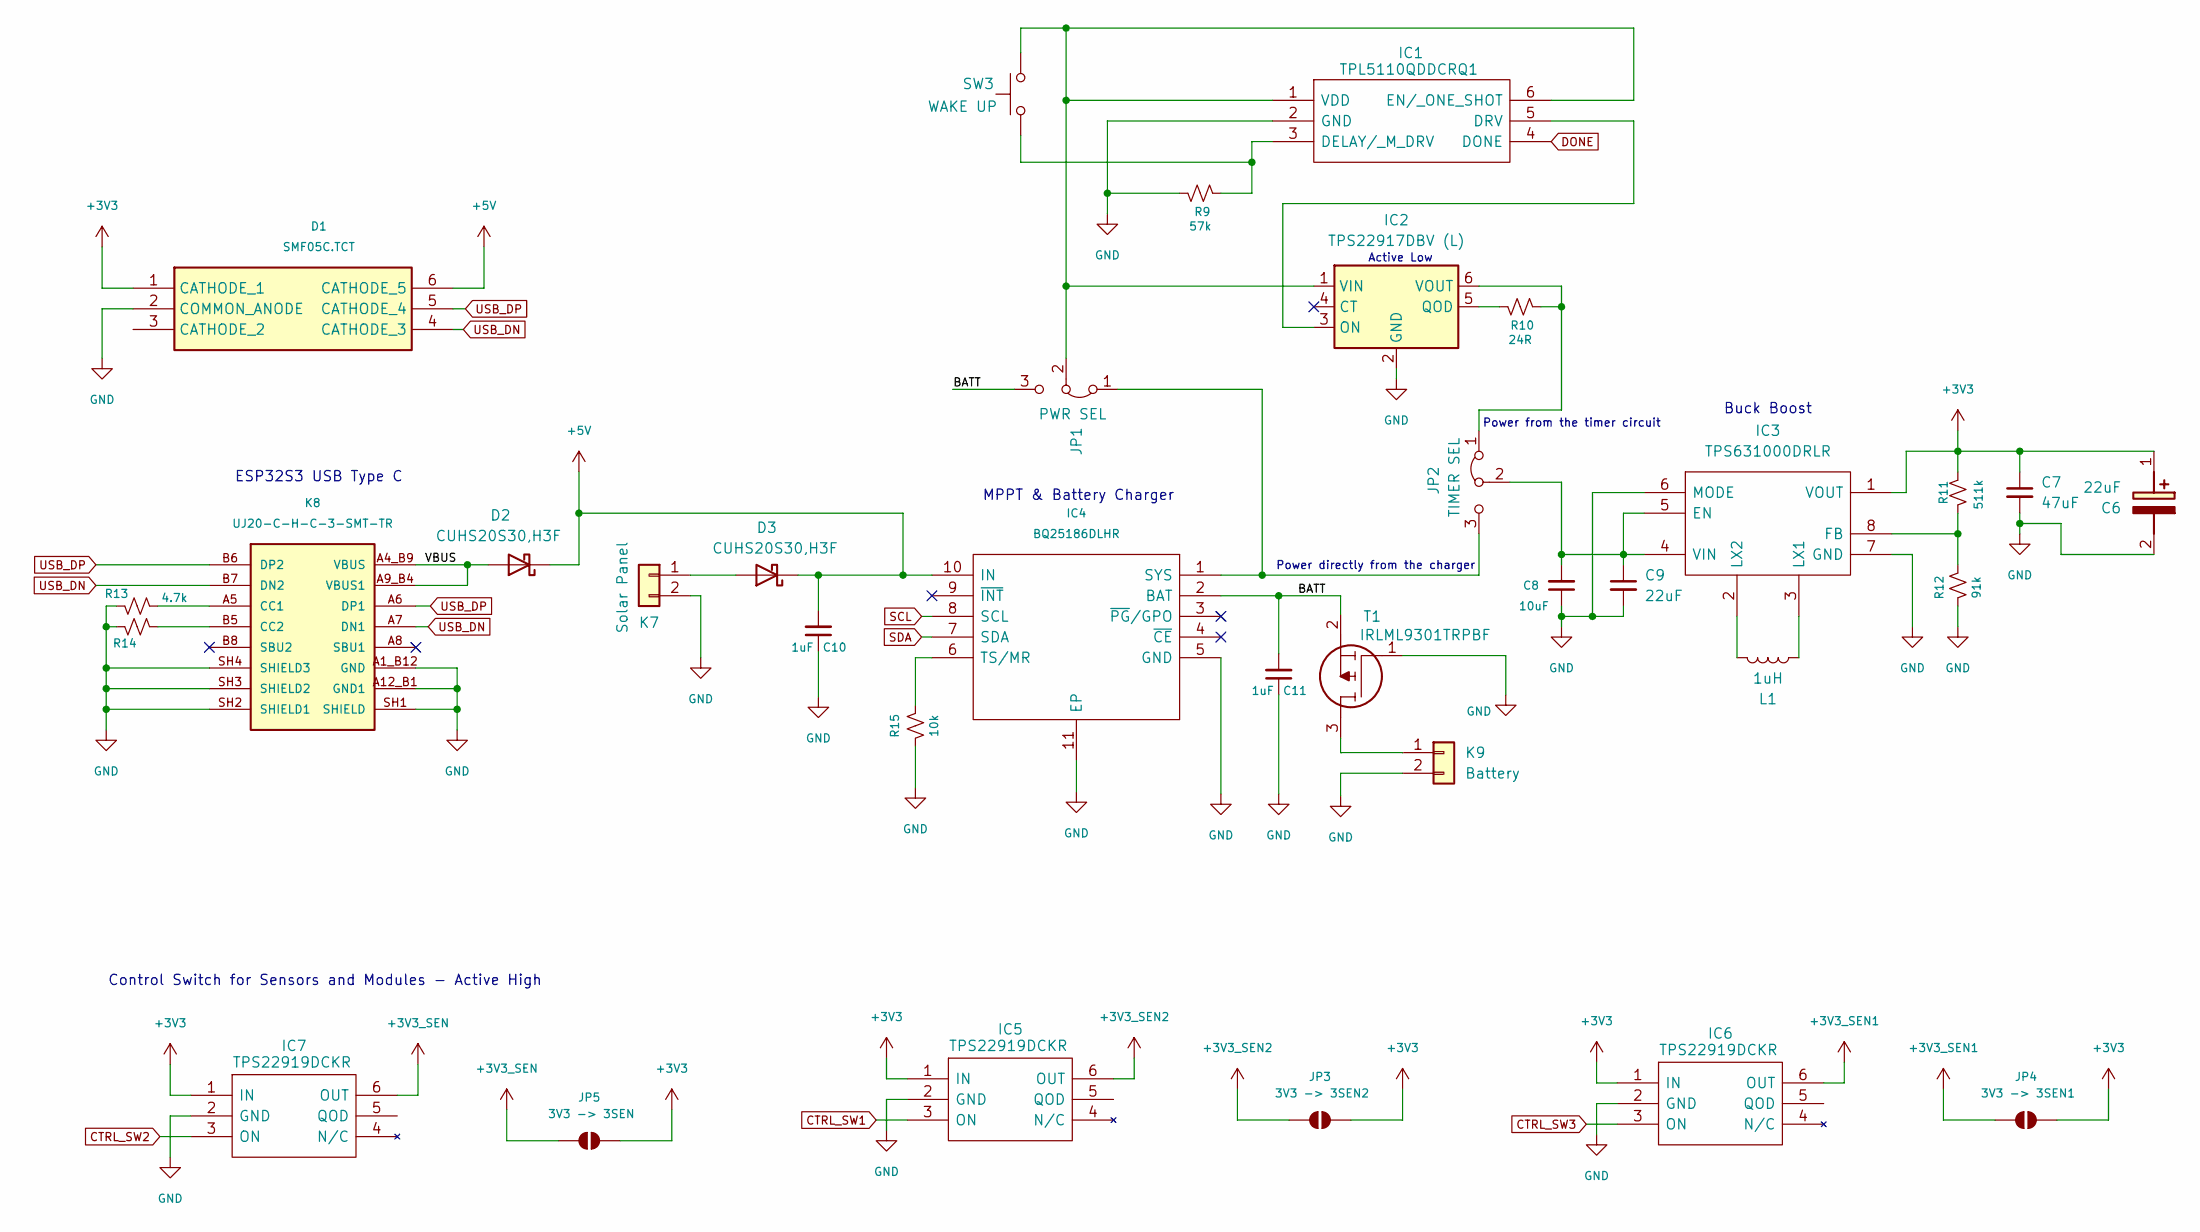
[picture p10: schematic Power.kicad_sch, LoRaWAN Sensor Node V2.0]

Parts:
C6: 22uF; CAPAE530X550N; Mouser Part Number 710-865080442004
C7: 47uF; C_0805_2012Metric; Manufacturer_Part_Number GRM219R60J476ME44
C8: 10uF; C_0402_1005Metric_Pad0.74x0.62mm_HandSolder; Mouser Part Number 81-GRM155R60J475ME7D
C9: 22uF; C_0603_1608Metric; Manufacturer_Part_Number GRM187R61A226ME15
C10, C11: 1uF; C_0402_1005Metric_Pad0.74x0.62mm_HandSolder; Mouser Part Number 81-GRM155R60J475ME7D
D1: SMF05C.TCT; SOT65P210X110-6N; Mouser Part Number 947-SMF05C.TCT
D2, D3: CUHS20S30,H3F; CUHS20S40H3F; Mouser Part Number 757-CUHS20S30H3F
IC1: TPL5110QDDCRQ1; SOT95P280X110-6N; Mouser Part Number 595-TPL5110QDDCRQ1
IC2: TPS22917DBV (L); SOT-23-6; Manufacturer_Part_Number TPS22917DBV
IC3: TPS631000DRLR; SOTFL50P160X60-8N; Mouser Part Number 595-TPS631000DRLR
IC4: BQ25186DLHR; SON40P220X200X80-11N; Mouser Part Number 595-BQ25186DLHR
IC5, IC6, IC7: TPS22919DCKR; SOT65P210X110-6N; Mouser Part Number 595-TPS22919DCKR
JP1: PWR SEL; PinHeader_1x03_P2.54mm_Vertical
JP2: TIMER SEL; PinHeader_1x03_P2.54mm_Vertical
JP3: 3V3 -> 3SEN2; SolderJumper-2_P1.3mm_Open_RoundedPad1.0x1.5mm
JP4: 3V3 -> 3SEN1; SolderJumper-2_P1.3mm_Open_RoundedPad1.0x1.5mm
JP5: 3V3 -> 3SEN; SolderJumper-2_P1.3mm_Open_RoundedPad1.0x1.5mm
K7: Solar Panel; JST_PH_S2B-PH-K_1x02_P2.00mm_Horizontal; Manufacturer_Part_Number JST_PH_S2B-PH-K_1x02_P2.00mm_Horizontal
K8: UJ20-C-H-C-3-SMT-TR; CUI_UJ20-C-H-C-3-SMT-TR; PARTREV 1.0
K9: Battery; JST_PH_S2B-PH-K_1x02_P2.00mm_Horizontal; Manufacturer_Part_Number JST_PH_S2B-PH-K_1x02_P2.00mm_Horizontal
L1: 1uH; 1285ASH1R0MP2; Mouser Part Number 81-DFE201610P-1R0MP2
R9: 57k; R_0402_1005Metric; Manufacturer_Part_Number RK73H1ETTP5762F; Mouser Part Number 660-RK73H1ETTP5762F
R10: 24R; R_0402_1005Metric; Manufacturer_Part_Number CRCW040224R0FKED; Mouser Part Number 71-CRCW040224R0FKED
R11: 511k; R_0402_1005Metric; Manufacturer_Part_Number ERJ-2RKF5113X; Mouser Part Number 667-ERJ-2RKF5113X
R12: 91k; R_0402_1005Metric; Manufacturer_Part_Number ERJ-2RKF9102X; Mouser Part Number 667-ERJ-2RKF9102X
R13, R14: 4.7k; R_0603_1608Metric; Manufacturer_Part_Number RCS06034K70FKEA; Mouser Part Number 71-RCS06034K70FKEA
R15: 10k; R_0402_1005Metric; Manufacturer_Part_Number RCS06034K70FKEA; Mouser Part Number 71-RCS06034K70FKEA
SW3: WAKE UP; SKRKAEE020; Manufacturer_Part_Number SKRKAEE020; Mouser Part Number SKRKAEE020
T1: IRLML9301TRPBF; SOT95P237X112-3N; Mouser Part Number 942-IRLML9301TRPBF

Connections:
+3V3: C6.1 (+), C7.1, D1.1 (CATHODE_1), IC3.1 (VOUT), IC5.1 (IN), IC6.1 (IN), IC7.1 (IN), JP3.2 (B), JP4.2 (B), JP5.2 (B), R11.2; also elsewhere on the board
+3V3_SEN: IC7.6 (OUT), JP5.1 (A); also elsewhere on the board
+3V3_SEN1: IC6.6 (OUT), JP4.1 (A); also elsewhere on the board
+3V3_SEN2: IC5.6 (OUT), JP3.1 (A); also elsewhere on the board
+5V: C10.2, D1.6 (CATHODE_5), D2.1 (K), D3.1 (K), IC4.10 (IN); also elsewhere on the board
/Power/BATT: C11.2, IC4.2 (BAT), JP1.3 (B), T1.2
/Power/VBUS: D2.2 (A), K8.A4_B9 (VBUS), K8.A9_B4 (VBUS1)
CTRL_SW1: IC5.3 (ON); also elsewhere on the board
CTRL_SW2: IC7.3 (ON); also elsewhere on the board
CTRL_SW3: IC6.3 (ON); also elsewhere on the board
DONE: IC1.4 (DONE); also elsewhere on the board
GND: C6.2 (-), C7.2, C8.1, C9.2, C10.1, C11.1, D1.2 (COMMON_ANODE), IC1.2 (GND), IC2.2 (GND), IC3.6 (MODE), IC3.7 (GND), IC4.5 (GND), IC4.11 (EP), IC5.2 (GND), IC6.2 (GND), IC7.2 (GND), K7.2, K8.A1_B12 (GND), K8.A12_B1 (GND1), K8.SH1 (SHIELD), K8.SH2 (SHIELD1), K8.SH3 (SHIELD2), K8.SH4 (SHIELD3), K9.2, R9.2, R12.1, R13.1, R14.1, R15.1, T1.1; also elsewhere on the board
I2C_DN: IC4.8 (SCL); also elsewhere on the board
I2C_DP: IC4.7 (SDA); also elsewhere on the board
unnamed: D3.2 (A), K7.1
unnamed: IC1.3 (DELAY/_M_DRV), R9.1, SW3.2
unnamed: IC1.5 (DRV), IC2.3 (ON)
unnamed: IC1.1 (VDD), IC1.6 (EN/_ONE_SHOT), IC2.1 (VIN), JP1.2 (C), SW3.1
unnamed: IC2.5 (QOD), R10.2
unnamed: IC2.6 (VOUT), JP2.1 (A), R10.1
unnamed: C8.2, C9.1, IC3.4 (VIN), IC3.5 (EN), JP2.2 (C)
unnamed: IC3.8 (FB), R11.1, R12.2
unnamed: IC3.3 (LX1), L1.2
unnamed: IC3.2 (LX2), L1.1
unnamed: IC4.1 (SYS), JP1.1 (A), JP2.3 (B)
unnamed: IC4.6 (TS/MR), R15.2
unnamed: K8.A5 (CC1), R13.2
unnamed: K8.B5 (CC2), R14.2
unnamed: K9.1, T1.3
USB_DN: D1.4 (CATHODE_3), K8.A7 (DN1), K8.B7 (DN2); also elsewhere on the board
USB_DP: D1.5 (CATHODE_4), K8.A6 (DP1), K8.B6 (DP2); also elsewhere on the board

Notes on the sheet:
Buck Boost
Power directly from the charger
ESP32S3 USB Type C
MPPT & Battery Charger
Power from the timer circuit
Active Low
Control Switch for Sensors and Modules - Active High

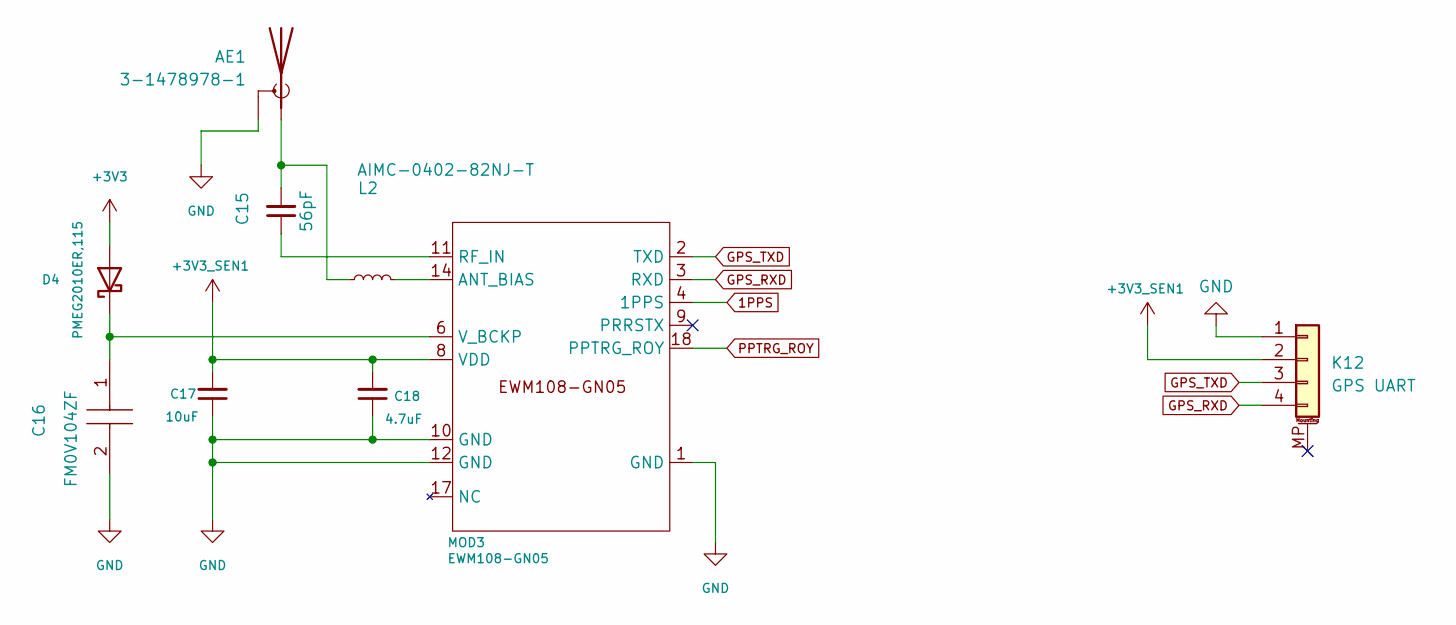
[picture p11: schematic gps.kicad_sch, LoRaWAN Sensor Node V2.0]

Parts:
AE1: 3-1478978-1; 314789781; Mouser Part Number 571-3-1478978-1
C15: 56pF; C_0603_1608Metric_Pad1.08x0.95mm_HandSolder; Manufacturer_Part_Number 600S560KT250T; Mouser Part Number 581-600S560KT250T
C16: FM0V104ZF; Mouser Part Number 80-FM0V104ZF
C17: 10uF; C_0402_1005Metric_Pad0.74x0.62mm_HandSolder; Mouser Part Number 81-GRM155R60J475ME7D
C18: 4.7uF; C_0402_1005Metric_Pad0.74x0.62mm_HandSolder; Mouser Part Number 81-GRM155R60J475ME7D
D4: PMEG2010ER,115; PMEG2010ER115; Mouser Part Number 771-PMEG2010ER115
K12: GPS UART; JST_PH_S4B-PH-SM4-TB_1x04-1MP_P2.00mm_Horizontal; Manufacturer_Part_Number Connector_JST:JST_PH_S4B-PH-SM4-TB_1x04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
L2: AIMC-0402-82NJ-T; INDC1005X65N; Manufacturer_Part_Number AIMC-0402-82NJ-T
MOD3: EWM108-GN05; PCBComponent_1; Manufacturer_Part_Number EWM108-GN05

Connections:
1PPS: MOD3.4 (1PPS); also elsewhere on the board
+3V3: D4.2 (A); also elsewhere on the board
+3V3_SEN1: C17.2, C18.2, K12.2, MOD3.8 (VDD); also elsewhere on the board
GND: AE1.1 (eShield), AE1.2 (Shield), AE1.3 (Shield), AE1.4 (Shield), C16.2, C17.1, C18.1, K12.1, MOD3.1 (GND), MOD3.10 (GND), MOD3.12 (GND); also elsewhere on the board
GPS_RXD: K12.4, MOD3.3 (RXD); also elsewhere on the board
GPS_TXD: K12.3, MOD3.2 (TXD); also elsewhere on the board
unnamed: AE1.5 (A), C15.2, L2.1
unnamed: C16.1, D4.1 (K), MOD3.6 (V_BCKP)
unnamed: L2.2, MOD3.14 (ANT_BIAS)
unnamed: C15.1, MOD3.11 (RF_IN)
PPTRG_ROY: MOD3.18 (PPTRG_ROY); also elsewhere on the board

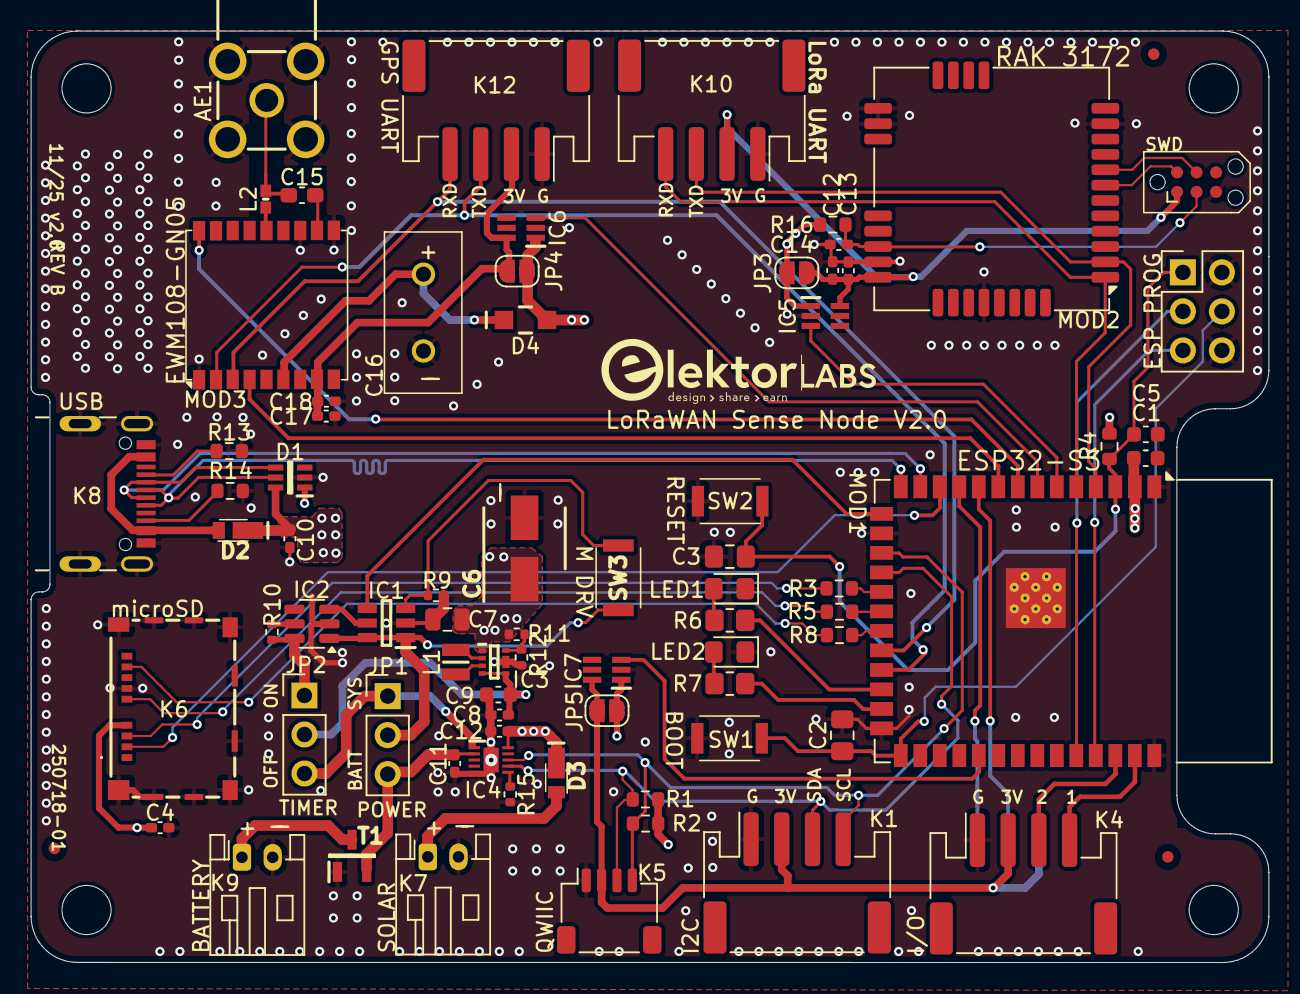
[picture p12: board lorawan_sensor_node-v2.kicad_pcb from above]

Board: 4 copper layers, 80.6 x 60.6 mm, 79 parts (1 on the bottom side), 63 nets.

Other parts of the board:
C12#2: 4.7uF; C_0402_1005Metric_Pad0.74x0.62mm_HandSolder

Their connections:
+5V: C12#2.2; also elsewhere on the board
GND: C12#2.1; also elsewhere on the board

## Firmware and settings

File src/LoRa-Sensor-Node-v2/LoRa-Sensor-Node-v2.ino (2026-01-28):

/*
 * LoRa-Sensor-Node-v2.ino
 *
 * Bench firmware for the ESP32-S3 sensor node:
 *   - Powers all rails and blinks LEDs to show GPS health.
 *   - Parses the Ebyte EWM108-GN05 NMEA stream via EbyteGpsParser.
 *   - Issues OTAA join commands to the Ebyte LoRa modem and watches for events.
 *   - Emits a human-readable status line and once-per-minute telemetry string.
 *   - Cycles peripherals and the ESP32-S3 through configurable deep-sleep windows (1 minute by default for bench tests).
 *
 * The sketch intentionally keeps logic shallow: configuration in config.h,
 * helpers for tagged logging and AT orchestration co-located, and generous
 * inline comments explaining each subsystem.
 */

#include <stdint.h>

enum class SystemFault : uint8_t;
struct FaultPattern;

#include <SPI.h>
#include <Wire.h>
#include <cstdio>
#include <cstring>
#include <esp_random.h>
#include <esp_sleep.h>
#include <driver/rtc_io.h>
#include <driver/gpio.h>

#include "Bq25186.h"
#include "config.h"
#include "EbyteGpsParser.h"
#include "LoraAtHelpers.h"
#include "SdCardLogger.h"
#include "TaggedStream.h"

namespace cfg = SensorNodeConfig;

HardwareSerial loraSerial(1);
HardwareSerial gpsSerial(2);
bool gpsSerialInitialized = false;

StreamTagState loraTag{"[LoRa] ", true};
StreamTagState gpsTag{"[GPS ] ", true};
LoraAtState loraState;

struct NullStream : public Stream {
  size_t write(uint8_t) override { return 1; }
  size_t write(const uint8_t *buffer, size_t size) override { return size; }
  int available() override { return 0; }
  int read() override { return -1; }
  int peek() override { return -1; }
  void flush() override {}
};

NullStream nullStream;
Stream *debugStream = &nullStream;

inline Stream &debugSerial() {
  return *debugStream;
}

EbyteGpsParser gpsParser;
const EbyteGpsStatus &gpsStatus = gpsParser.getStatus();
SdCardLoggerState sdLoggerState;
Bq25186 charger;
constexpr Bq25186::SysMode kDefaultSysMode = Bq25186::SysMode::kAutoVinOrBattery;

constexpr SdCardLoggerConfig kSdLoggerConfig{
    cfg::kSdCsPin,
    cfg::kSdSckPin,
    cfg::kSdMisoPin,
    cfg::kSdMosiPin,
    cfg::kSdLogFilename,
};

char gpsSentenceBuffer[160];
size_t gpsSentenceLength = 0;
bool loraSendFailed = false;
bool chargerReady = false;
unsigned long lastChargerPollMs = 0;

enum class RunStage : uint8_t { AwaitGpsLock, AwaitJoin, AwaitTelemetry, AwaitPostSend };

RunStage runStage = RunStage::AwaitGpsLock;
unsigned long stageStartMs = 0;

constexpr unsigned long kGpsFreshnessWindowMs = 5000;
constexpr unsigned long kGpsCommandSettleMs = 50;

bool gpsFixIsFresh(unsigned long now) {
  return gpsStatus.fixValid &&
         gpsStatus.hasSentence &&
         (now - gpsStatus.lastUpdateMs) < kGpsFreshnessWindowMs;
}

enum class SystemFault : uint8_t { None, Gps, Lora };

struct FaultPattern {
  uint8_t flashes;
  unsigned long onMs;
  unsigned long offMs;
  unsigned long pauseMs;
};

constexpr FaultPattern kGpsFaultPattern{2, 120, 120, 500};
constexpr FaultPattern kLoraFaultPattern{3, 120, 120, 600};

struct FaultBlinkState {
  SystemFault fault = SystemFault::None;
  bool redOn = false;
  bool pausePhase = false;
  uint8_t flashesRemaining = 0;
  unsigned long lastTransitionMs = 0;
};

FaultBlinkState faultBlinkState;

constexpr char kHexDigits[] = "0123456789ABCDEF";

void setRunStage(RunStage nextStage);
bool gpsSendBinaryPacket(uint8_t groupId, uint8_t messageId, const uint8_t *payload, size_t payloadLength);
void gpsRequestSleep(uint32_t periodMs, uint8_t action);
void gpsRequestStart(uint8_t mode);
void gpsEnterBackupMode();
void gpsExitBackupMode();
void configureStatusLedPins();
inline void setStatusLed(uint8_t pin, bool high);
inline void setRedLed(bool high);
inline void setGreenLed(bool high);

void releaseHighSpeedPeripherals() {
  loraSerial.end();
  if (gpsSerialInitialized) {
    gpsSerial.flush();
  }
  gpsSerial.end();
  gpsSerialInitialized = false;
  Wire.end();
  SPI.end();
}

void configurePinsForSleep() {
  const uint8_t lowPins[] = {
      cfg::kPinI2cEnable,
      cfg::kPinLoraEnable,
      cfg::kPinGpsEnable,
      cfg::kLedRedPin,
      cfg::kLedGreenPin,
      cfg::kSdCsPin,
  };
  for (uint8_t pin : lowPins) {
    pinMode(pin, INPUT_PULLDOWN);
  }

  const gpio_num_t holdPins[] = {
      static_cast<gpio_num_t>(cfg::kPinI2cEnable),
      static_cast<gpio_num_t>(cfg::kPinLoraEnable),
      static_cast<gpio_num_t>(cfg::kPinGpsEnable),
  };
  for (gpio_num_t pin : holdPins) {
    gpio_hold_en(pin);
  }
  gpio_deep_sleep_hold_en();
}

void clearSleepHolds() {
  const gpio_num_t holdPins[] = {
      static_cast<gpio_num_t>(cfg::kPinI2cEnable),
      static_cast<gpio_num_t>(cfg::kPinLoraEnable),
      static_cast<gpio_num_t>(cfg::kPinGpsEnable),
  };
  for (gpio_num_t pin : holdPins) {
    gpio_hold_dis(pin);
  }
  gpio_deep_sleep_hold_dis();
}

void setRunStage(RunStage nextStage) {
  runStage = nextStage;
  stageStartMs = millis();
}

void configureStatusLedPins() {
  if (cfg::kEnableStatusLeds) {
    pinMode(cfg::kLedRedPin, OUTPUT);
    pinMode(cfg::kLedGreenPin, OUTPUT);
    digitalWrite(cfg::kLedRedPin, LOW);
    digitalWrite(cfg::kLedGreenPin, LOW);
  } else {
    pinMode(cfg::kLedRedPin, INPUT);
    pinMode(cfg::kLedGreenPin, INPUT);
    digitalWrite(cfg::kLedRedPin, LOW);    // Disable pull-ups.
    digitalWrite(cfg::kLedGreenPin, LOW);
  }
}

inline void setStatusLed(uint8_t pin, bool high) {
  if (!cfg::kEnableStatusLeds) {
    return;
  }
  digitalWrite(pin, high ? HIGH : LOW);
}

inline void setRedLed(bool high) {
  setStatusLed(cfg::kLedRedPin, high);
}

inline void setGreenLed(bool high) {
  setStatusLed(cfg::kLedGreenPin, high);
}

bool gpsSendBinaryPacket(uint8_t groupId,
                         uint8_t messageId,
                         const uint8_t *payload,
                         size_t payloadLength) {
  if (!gpsSerialInitialized) {
    return false;
  }

  constexpr uint8_t kStart[2] = {0xF1, 0xD9};
  uint8_t header[4] = {
      groupId,
      messageId,
      static_cast<uint8_t>(payloadLength & 0xFF),
      static_cast<uint8_t>((payloadLength >> 8) & 0xFF),
  };

  auto checksumBytes = [](const uint8_t *data, size_t length, uint8_t &ck1, uint8_t &ck2) {
    for (size_t i = 0; i < length; ++i) {
      ck1 = (ck1 + data[i]) & 0xFF;
      ck2 = (ck2 + ck1) & 0xFF;
    }
  };

  uint8_t ck1 = 0;
  uint8_t ck2 = 0;
  checksumBytes(header, sizeof(header), ck1, ck2);
  if (payload != nullptr && payloadLength > 0) {
    checksumBytes(payload, payloadLength, ck1, ck2);
  }

  gpsSerial.write(kStart, sizeof(kStart));
  gpsSerial.write(header, sizeof(header));
  if (payload != nullptr && payloadLength > 0) {
    gpsSerial.write(payload, payloadLength);
  }
  const uint8_t checksum[2] = {ck1, ck2};
  gpsSerial.write(checksum, sizeof(checksum));
  gpsSerial.flush();
  return true;
}

void gpsRequestSleep(uint32_t periodMs, uint8_t action) {
  if (!gpsSerialInitialized || periodMs == 0) {
    return;
  }
  uint8_t payload[5];
  payload[0] = static_cast<uint8_t>(periodMs & 0xFF);
  payload[1] = static_cast<uint8_t>((periodMs >> 8) & 0xFF);
  payload[2] = static_cast<uint8_t>((periodMs >> 16) & 0xFF);
  payload[3] = static_cast<uint8_t>((periodMs >> 24) & 0xFF);
  payload[4] = action;

  debugSerial().print("[GPS ] CFG-SLEEP action=0x");
  debugSerial().print(action, HEX);
  debugSerial().print(" for ");
  debugSerial().print(periodMs);
  debugSerial().println(" ms.");

  if (gpsSendBinaryPacket(0x06, 0x41, payload, sizeof(payload))) {
    delay(kGpsCommandSettleMs);
  }
}

void gpsRequestStart(uint8_t mode) {
  if (!gpsSerialInitialized || mode == 0xFF) {
    return;
  }
  uint8_t payload = mode;
  debugSerial().print("[GPS ] CFG-CMD mode=0x");
  debugSerial().print(mode, HEX);
  debugSerial().println(" (wake).");
  if (gpsSendBinaryPacket(0x06, 0x40, &payload, sizeof(payload))) {
    delay(kGpsCommandSettleMs);
  }
}

void gpsEnterBackupMode() {
  if (!cfg::kGpsPowerConfig.enabled) {
    return;
  }
  gpsRequestSleep(cfg::kGpsPowerConfig.sleepDurationMs,
                  cfg::kGpsPowerConfig.sleepAction);
}

void gpsExitBackupMode() {
  if (!cfg::kGpsPowerConfig.enabled) {
    return;
  }
  gpsRequestStart(cfg::kGpsPowerConfig.wakeMode);
}

void setPeripheralPower(bool enabled) {
  const int level = enabled ? HIGH : LOW;
  digitalWrite(cfg::kPinI2cEnable, level);
  digitalWrite(cfg::kPinLoraEnable, level);
  digitalWrite(cfg::kPinGpsEnable, level);
}

void powerUpPeripherals() {
  debugSerial().println("[Pwr ] Enabling power rails.");
  setPeripheralPower(true);
  delay(cfg::kPeripheralWarmupMs);
}

void powerDownPeripherals() {
  debugSerial().println("[Pwr ] Disabling power rails.");
  setPeripheralPower(false);
  setRedLed(false);
  setGreenLed(false);
}

void logWakeReason() {
  const esp_sleep_wakeup_cause_t cause = esp_sleep_get_wakeup_cause();
  const char *description = "power-on/reset";
  switch (cause) {
    case ESP_SLEEP_WAKEUP_TIMER:
      description = "RTC timer";
      break;
    case ESP_SLEEP_WAKEUP_UNDEFINED:
      description = "undefined";
      break;
    case ESP_SLEEP_WAKEUP_EXT0:
    case ESP_SLEEP_WAKEUP_EXT1:
    case ESP_SLEEP_WAKEUP_TOUCHPAD:
    case ESP_SLEEP_WAKEUP_ULP:
    case ESP_SLEEP_WAKEUP_GPIO:
      description = "external trigger";
      break;
    default:
      break;
  }
  debugSerial().print("[Pwr ] Wake cause: ");
  debugSerial().println(description);
}

void enterDeepSleep(const char *reason) {
  if (!cfg::kEnableDeepSleep) {
    debugSerial().print("[Pwr ] Deep sleep disabled; would have slept because: ");
    debugSerial().println(reason ? reason : "(unspecified)");
    setRunStage(RunStage::AwaitGpsLock);
    return;
  }
  debugSerial().print("[Pwr ] Entering deep sleep for ");
  debugSerial().print(cfg::kDeepSleepIntervalUs / 1000000ULL);
  debugSerial().print(" seconds (reason: ");
  debugSerial().print(reason);
  debugSerial().println(")");
  gpsEnterBackupMode();
  if (cfg::kEnableDebugSerial) {
    Serial.flush();
  }
  releaseHighSpeedPeripherals();
  if (cfg::kEnableDebugSerial) {
    Serial.end();
  }
  powerDownPeripherals();
  configurePinsForSleep();
  esp_sleep_pd_config(ESP_PD_DOMAIN_RTC_PERIPH, ESP_PD_OPTION_OFF);
#ifdef ESP_PD_DOMAIN_RTC_FAST_MEM
  esp_sleep_pd_config(ESP_PD_DOMAIN_RTC_FAST_MEM, ESP_PD_OPTION_OFF);
#endif
#ifdef ESP_PD_DOMAIN_RTC_SLOW_MEM
  esp_sleep_pd_config(ESP_PD_DOMAIN_RTC_SLOW_MEM, ESP_PD_OPTION_OFF);
#endif
  esp_sleep_enable_timer_wakeup(cfg::kDeepSleepIntervalUs);
  esp_deep_sleep_start();
}

void handleGpsLockStage() {
  const unsigned long now = millis();
  if (gpsFixIsFresh(now)) {
    debugSerial().println("[GPS ] Fix acquired; exiting cold start.");
    setRunStage(RunStage::AwaitJoin);
    return;
  }

  const bool coldStartElapsed =
      cfg::kGpsColdStartMs == 0 || (now - stageStartMs) >= cfg::kGpsColdStartMs;
  if (!coldStartElapsed) {
    return;
  }

  if (cfg::kGpsLockTimeoutMs > 0 &&
      (now - stageStartMs) >= cfg::kGpsLockTimeoutMs) {
    debugSerial().println("[GPS ] Cold start timeout; continuing without valid fix.");
    setRunStage(RunStage::AwaitJoin);
  }
}

void handleJoinStage() {
  if (!loraJoined(loraState)) {
    loraStartJoin(loraState, cfg::kLoraJoinRetryMs);
  }

  if (loraJoined(loraState)) {
    debugSerial().println("[LoRa] Join complete; sending telemetry.");
    setRunStage(RunStage::AwaitTelemetry);
    return;
  }

  const unsigned long now = millis();
  if (cfg::kJoinTimeoutMs > 0 &&
      (now - stageStartMs) >= cfg::kJoinTimeoutMs) {
    debugSerial().println("[LoRa] Join timeout; sleeping before retry.");
    enterDeepSleep("join timeout");
  }
}

void handleTelemetryStage() {
  const unsigned long now = millis();
  if (!gpsFixIsFresh(now)) {
    debugSerial().println("[GPS ] No fresh fix; sending best-effort telemetry.");
  }

  if (sendTelemetryFrame()) {
    setRunStage(RunStage::AwaitPostSend);
  } else {
    debugSerial().println("[LoRa] Telemetry failed; entering sleep to retry next wake.");
    enterDeepSleep("telemetry failure");
  }
}

void handlePostSendStage() {
  const unsigned long now = millis();
  if (now - stageStartMs >= cfg::kPostSendHoldMs) {
    enterDeepSleep("telemetry complete");
  }
}

// State flow cheat sheet:
//   AwaitGpsLock  -> Wait for fix (respect cold-start window).
//   AwaitJoin     -> Retry OTAA join until accepted (or timeout -> sleep).
//   AwaitTelemetry-> Send telemetry immediately after join.
//   AwaitPostSend -> Hold a few ms for logs, then deep sleep.
void runStateMachine() {
  switch (runStage) {
    case RunStage::AwaitGpsLock:
      handleGpsLockStage();
      break;
    case RunStage::AwaitJoin:
      handleJoinStage();
      break;
    case RunStage::AwaitTelemetry:
      handleTelemetryStage();
      break;
    case RunStage::AwaitPostSend:
      handlePostSendStage();
      break;
  }
}

void printChargerTelemetry(const Bq25186::Telemetry &telemetry) {
  debugSerial().print("[Chg ] SYS=");
  debugSerial().print(Bq25186::sysModeDescription(telemetry.sysMode));
  debugSerial().print(" | VbatTarget=");
  debugSerial().print(telemetry.batteryRegVoltage, 3);
  debugSerial().print(" V | IchgTarget=");
  debugSerial().print(telemetry.fastChargeCurrentMa, 0);
  debugSerial().print(" mA | ILIM=");
  debugSerial().print(telemetry.inputCurrentLimitMa, 0);
  debugSerial().print(" mA | Charge=");
  debugSerial().print(Bq25186::chargeStateDescription(telemetry.stat0.chargeState));
  debugSerial().print(" (");
  debugSerial().print(telemetry.chargeEnabled ? "enabled" : "disabled");
  debugSerial().print(") | TS=");
  debugSerial().print(Bq25186::tsStatusDescription(telemetry.stat1.tsStatus));
  debugSerial().print(" | PG=");
  debugSerial().print(telemetry.stat0.vinPowerGood ? "Y" : "N");
  debugSerial().print(" | WDT=");
  debugSerial().print(telemetry.watchdogEnabled ? "Y" : "N");
  if (telemetry.faults.any()) {
    debugSerial().print(" | Faults:");
    if (telemetry.faults.tsFault) {
      debugSerial().print(" TS");
    }
    if (telemetry.faults.ilimFault) {
      debugSerial().print(" ILIM");
    }
    if (telemetry.faults.vdppmFault) {
      debugSerial().print(" VDPPM");
    }
    if (telemetry.faults.vindpmFault) {
      debugSerial().print(" VINDPM");
    }
    if (telemetry.faults.thermalRegulationFlag) {
      debugSerial().print(" THERM");
    }
    if (telemetry.faults.vinOvpFault) {
      debugSerial().print(" VIN_OVP");
    }
    if (telemetry.faults.buvloFault) {
      debugSerial().print(" BUVLO");
    }
    if (telemetry.faults.batOcpFault) {
      debugSerial().print(" BAT_OCP");
    }
  }
  debugSerial().println();
}

void pollCharger() {
  if (!chargerReady) {
    return;
  }

  const unsigned long now = millis();
  if (now - lastChargerPollMs < 2000) {
    return;
  }
  lastChargerPollMs = now;

  Bq25186::Telemetry telemetry;
  if (!charger.readTelemetry(telemetry)) {
    debugSerial().println("[Chg ] Failed to read BQ25186 registers.");
    return;
  }
  printChargerTelemetry(telemetry);
}

// Converts an ASCII payload into uppercase hex so it can be fed to AT+SEND.
void asciiToHex(const char *input, char *output, size_t outputSize) {
  size_t outIndex = 0;
  for (size_t i = 0; input[i] != '\0'; ++i) {
    const uint8_t value = static_cast<uint8_t>(input[i]);
    if (outIndex + 2 >= outputSize) {
      break;
    }
    output[outIndex++] = kHexDigits[(value >> 4) & 0x0F];
    output[outIndex++] = kHexDigits[value & 0x0F];
  }
  output[outIndex] = '\0';
}

// Prints a single-line summary of the most recent GPS sentence.
void printGpsSummary() {
  char summary[196];
  snprintf(summary,
           sizeof(summary),
           "[GPS ] UTC %s %s | %s | Sats %u | Lat %.5f | Lon %.5f | Alt %.1f m | Speed %.2f km/h",
           gpsStatus.timeUtc,
           gpsStatus.dateUtc,
           gpsStatus.fixValid ? "Fix OK" : "No Fix",
           gpsStatus.satelliteCount,
           gpsStatus.latitudeDeg,
           gpsStatus.longitudeDeg,
           gpsStatus.altitudeMeters,
           gpsStatus.speedKmh);

  debugSerial().println(summary);
  sdLoggerLogLine(sdLoggerState, summary);
  sdLoggerLogCsv(sdLoggerState, gpsStatus);
}

// Dumps the provisioned LoRaWAN identifiers so they are captured in the log.
void printLoraInfo() {
  debugSerial().println("[LoRa] Provisioned credentials:");
  debugSerial().print("[LoRa]   DevEUI : ");
  debugSerial().println(cfg::kLoraCredentials.devEui);
  debugSerial().print("[LoRa]   AppEUI : ");
  debugSerial().println(cfg::kLoraCredentials.appEui);
  debugSerial().print("[LoRa]   AppKey : ");
  debugSerial().println(cfg::kLoraCredentials.appKey);
  debugSerial().print("[LoRa] Will transmit with AT+SEND=");
  debugSerial().print(cfg::kLoraRadioSettings.sendPort);
  debugSerial().println(":<HEX_PAYLOAD>");
}

// Formats the telemetry payload and hands it to the LoRa helper.
bool sendTelemetryFrame() {
  if (!loraJoined(loraState)) {
    debugSerial().println("[LoRa] Skipping telemetry: waiting for +EVT:JOINED.");
    loraStartJoin(loraState, cfg::kLoraJoinRetryMs);
    return false;
  }

  const float temperatureC = random(180, 350) / 10.0f;   // Simulated 18-35 C
  const float humidityPct = random(300, 900) / 10.0f;    // Simulated 30-90 %
  const char *fixState = gpsStatus.fixValid ? "FIX" : "NO_FIX";

  char payload[160];
  snprintf(payload, sizeof(payload),
           "ALT=%.1f,TEMP=%.1f,HUM=%.1f,STATUS=%s",
           gpsStatus.altitudeMeters, temperatureC, humidityPct, fixState);

  debugSerial().print("[LoRa] Sending telemetry: ");
  debugSerial().println(payload);

  char hexPayload[320];
  asciiToHex(payload, hexPayload, sizeof(hexPayload));

  if (!loraSendHexPayload(loraState,
                          cfg::kLoraRadioSettings.sendPort,
                          hexPayload,
                          cfg::kLoraRadioSettings.sendResponse,
                          6000)) {
    debugSerial().println("[LoRa] Telemetry send failed.");
    loraSendFailed = true;
    return false;
  }
  loraSendFailed = false;
  return true;
}

// Fires once per minute as long as we've seen at least one GPS fix.
void processGpsSentence(const char *sentence) {
  if (gpsParser.processSentence(sentence)) {
    printGpsSummary();
  }
}

// Collects each GPS byte until CR/LF, optionally echoing the raw stream.
void handleGpsByte(int byteValue) {
  if (cfg::kShowRawGps) {
    printTaggedByte(debugSerial(), gpsTag, byteValue);
  }

  if (byteValue == '\n') {
    gpsSentenceBuffer[gpsSentenceLength] = '\0';
    if (gpsSentenceLength > 0) {
      processGpsSentence(gpsSentenceBuffer);
    }
    gpsSentenceLength = 0;
  } else if (byteValue != '\r') {
    if (gpsSentenceLength < sizeof(gpsSentenceBuffer) - 1) {
      gpsSentenceBuffer[gpsSentenceLength++] = static_cast<char>(byteValue);
    } else {
      gpsSentenceLength = 0;
    }
  }
}

const FaultPattern &patternFor(SystemFault fault) {
  return (fault == SystemFault::Lora) ? kLoraFaultPattern : kGpsFaultPattern;
}

SystemFault determineFault(unsigned long now) {
  const bool gpsHealthy = gpsFixIsFresh(now);
  const bool loraIsJoined = loraJoined(loraState);
  const bool withinJoinGrace = !loraIsJoined &&
                               (loraState.lastJoinAttemptMs == 0 ||
                                (now - loraState.lastJoinAttemptMs) < cfg::kLoraJoinRetryMs);
  const bool loraHealthy = !loraSendFailed && (loraIsJoined || withinJoinGrace);

  if (!loraHealthy) {
    return SystemFault::Lora;
  }
  if (!gpsHealthy) {
    return SystemFault::Gps;
  }
  return SystemFault::None;
}

void resetFaultBlinkState(SystemFault fault, unsigned long now) {
  faultBlinkState.fault = fault;
  faultBlinkState.redOn = false;
  faultBlinkState.pausePhase = false;
  faultBlinkState.flashesRemaining =
      (fault == SystemFault::None) ? 0 : patternFor(fault).flashes;
  faultBlinkState.lastTransitionMs = now;
  setRedLed(false);
}

void driveFaultPattern(SystemFault fault, unsigned long now) {
  if (!cfg::kEnableStatusLeds) {
    return;
  }

  if (fault == SystemFault::None) {
    setRedLed(false);
    setGreenLed(true);
    resetFaultBlinkState(SystemFault::None, now);
    return;
  }

  setGreenLed(false);

  if (fault != faultBlinkState.fault) {
    resetFaultBlinkState(fault, now);
  }

  const FaultPattern &pattern = patternFor(fault);

  if (faultBlinkState.pausePhase) {
    if (now - faultBlinkState.lastTransitionMs >= pattern.pauseMs) {
      faultBlinkState.pausePhase = false;
      faultBlinkState.flashesRemaining = pattern.flashes;
      faultBlinkState.lastTransitionMs = now;
    }
    return;
  }

  if (faultBlinkState.redOn) {
    if (now - faultBlinkState.lastTransitionMs >= pattern.onMs) {
      faultBlinkState.redOn = false;
      faultBlinkState.lastTransitionMs = now;
      setRedLed(false);
      if (faultBlinkState.flashesRemaining > 0) {
        faultBlinkState.flashesRemaining--;
      }
      if (faultBlinkState.flashesRemaining == 0) {
        faultBlinkState.pausePhase = true;
        faultBlinkState.lastTransitionMs = now;
      }
    }
    return;
  }

  if (faultBlinkState.flashesRemaining == 0) {
    faultBlinkState.pausePhase = true;
    faultBlinkState.lastTransitionMs = now;
    return;
  }

  if (now - faultBlinkState.lastTransitionMs >= pattern.offMs) {
    faultBlinkState.redOn = true;
    faultBlinkState.lastTransitionMs = now;
    setRedLed(true);
  }
}

void updateStatusIndicators() {
  if (!cfg::kEnableStatusLeds) {
    return;
  }
  const unsigned long now = millis();
  const SystemFault fault = determineFault(now);
  driveFaultPattern(fault, now);
}
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
void loop() {}

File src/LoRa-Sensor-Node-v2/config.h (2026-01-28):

#pragma once

#include <Arduino.h>

namespace SensorNodeConfig {

// Peripheral power-control GPIOs.
constexpr uint8_t kPinI2cEnable = 38;
constexpr uint8_t kPinLoraEnable = 6;
constexpr uint8_t kPinGpsEnable = 7;

// Indicator LEDs.
constexpr uint8_t kLedRedPin = 48;
constexpr uint8_t kLedGreenPin = 47;

// I2C bus shared with the charger IC.
constexpr int kI2cSdaPin = 10;
constexpr int kI2cSclPin = 9;

// SD card over SPI.
constexpr uint8_t kSdMosiPin = 11;  // MOSI (SD-MO)
constexpr uint8_t kSdSckPin = 12;   // SCK
constexpr uint8_t kSdMisoPin = 13;  // MISO (SD-MI)
constexpr uint8_t kSdCsPin = 8;     // Chip select
constexpr const char *kSdLogFilename = "/gps-log.csv";

// UART assignments.
constexpr int kLoraRxPin = 4;
constexpr int kLoraTxPin = 5;
constexpr uint32_t kLoraBaud = 115200;

constexpr int kGpsRxPin = 21;
constexpr int kGpsTxPin = 14;
constexpr uint32_t kGpsBaud = 115200;

// Telemetry + power cadence.
constexpr unsigned long kJoinTimeoutMs = 0;              // 0 = wait indefinitely for OTAA.
constexpr unsigned long kSensorAcquisitionMs = 15000;    // Fallback if GPS never reports.
constexpr unsigned long kPostSendHoldMs = 3000;          // Log/flush delay before sleeping.
constexpr unsigned long kPeripheralWarmupMs = 1500;      // Allow power-rail settling.
constexpr uint64_t kDeepSleepIntervalUs = 600ULL * 1000000ULL;  // 1 minute test interval.
constexpr unsigned long kLoraJoinRetryMs = 15000;        // Retry OTAA command every 15 s.
constexpr unsigned long kGpsColdStartMs = 60000;         // Minimum wait before attempting LoRa join.
constexpr unsigned long kGpsLockTimeoutMs = 180000;      // Proceed even without fix after 3 minutes.

// Raw GPS logging toggle.
constexpr bool kShowRawGps = false;
constexpr bool kEnableDebugSerial = true;
constexpr bool kEnableDeepSleep = true;  // Set false for bench loops without ESP32 deep sleep.
constexpr bool kEnableStatusLeds = false; // Disable to force both LEDs off for low-power tests.
constexpr float kChargeTargetCurrentMa = 520.0f;   // Mid-scale fast-charge current (5-1000 mA range).
constexpr float kInputCurrentLimitMa = 665.0f;     // BQ25186 ILIM step just above 500 mA.

// Allystar GNSS power profile (CFG-SLEEP / CFG-CMD per T-5-2302 spec).
struct AllystarGpsPowerConfig {
  bool enabled;              // Master toggle for Allystar sleep/wake commands.
  uint32_t sleepDurationMs;  // Used when sending CFG-SLEEP (0 disables the command).
  uint8_t sleepAction;       // 0: sleep, 1: deep sleep, 3: power down, etc.
  uint8_t wakeMode;          // CFG-CMD mode (0x11 = Start, 0x03 = hot start, etc.).
};

constexpr AllystarGpsPowerConfig kGpsPowerConfig{
    true,    // Enable GPS sleep/wake commands by default.
    90000,   // Keep Allystar in deep sleep for 90 seconds while rails are off.
    0x01,    // Use action=1 (deep sleep) before cutting power.
    0x11,    // Issue CFG-CMD start to wake after rails return.
};

// LoRaWAN identifiers/keys.
struct LoraCredentials {
  const char *devEui;
  const char *appEui;
  const char *appKey;
};

constexpr LoraCredentials kLoraCredentials{
    "xxxxx",
    "xxxxx",
    "xxxxx",
};

// LoRaWAN radio settings.
struct LoraRadioSettings {
  const char *region;
  const char *channelPlan;
  int defaultPort;
  int sendPort;
  const char *sendResponse;
};

constexpr LoraRadioSettings kLoraRadioSettings{
    "EU868",
    "0-2",
    2,
    2,
    "OK",
};

}  // namespace SensorNodeConfig

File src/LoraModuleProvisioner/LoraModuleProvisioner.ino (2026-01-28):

/*
 * LoraModuleProvisioner.ino
 *
 * Minimal console helper that simply bridges USB serial to the Ebyte LoRa
 * modem and prints four common provisioning commands. The operator copies each
 * command into the serial monitor to configure the modem manually.
 */

#include <Arduino.h>

#include "../LoRa-SenseNode-v2/config.h"

namespace cfg = SensorNodeConfig;

HardwareSerial loraSerial(1);

void printInstructions() {
  Serial.println();
  Serial.println("LoRa Module Manual Provisioning");
  Serial.println("--------------------------------");
  Serial.println("Copy each command below into the serial monitor (press Enter after each line):");
  Serial.println();
  Serial.println("1) Read DevEUI:");
  Serial.println("   AT+DEVEUI?");
  Serial.println();
  Serial.println("2) Program your JoinEUI (replace <JOIN_EUI> with 16 hex chars):");
  Serial.println("   AT+APPEUI=<JOIN_EUI>");
  Serial.println();
  Serial.println("3) Program your AppKey (replace <APP_KEY> with 32 hex chars):");
  Serial.println("   AT+APPKEY=<APP_KEY>");
  Serial.println();
  Serial.println("4) Attempt an OTAA join:");
  Serial.println("   AT+JOIN");
  Serial.println();
  Serial.println("After the modem reports +EVT:JOINED you can send a test payload, e.g.:");
  Serial.println("   AT+SEND=2:54455354");
  Serial.println();
  Serial.println("Console is now in passthrough mode. Type commands to talk directly to the modem.");
  Serial.println();
}

void setup() {
  pinMode(cfg::kPinLoraEnable, OUTPUT);
  digitalWrite(cfg::kPinLoraEnable, HIGH);

  Serial.begin(115200);
  while (!Serial) {
    delay(10);
  }

  loraSerial.begin(cfg::kLoraBaud, SERIAL_8N1, cfg::kLoraRxPin, cfg::kLoraTxPin);
  delay(50);
  loraSerial.print("AT\r\n");  // Wake the modem UART.

  printInstructions();
}

void loop() {
  while (Serial.available() > 0) {
    loraSerial.write(Serial.read());
  }
  while (loraSerial.available() > 0) {
    Serial.write(loraSerial.read());
  }
}

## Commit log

2026-01-28 Add LoRaWAN Sensor Node v2 hardware and firmware
    Initial commit of hardware design files for the LoRaWAN Sensor Node v2, including KiCad schematics, PCB layout, BOMs (old and new), and supporting documentation. Also adds initial firmware source fil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
    [BOM-new.csv, BOM-old.csv, Power.kicad_sch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]
2026-01-28 Revise README for LoRa-Sensor-Node-v2
    Updated project name and expanded README with detailed features, hardware components, configuration, operation flow, troubleshooting, development guidelines, and contributing instructions.

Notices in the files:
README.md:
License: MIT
